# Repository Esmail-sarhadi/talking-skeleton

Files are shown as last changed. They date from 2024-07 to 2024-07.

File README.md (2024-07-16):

# Talking Skeleton with Bluetooth, RF, and MP3 Playback

## Features
- **Bluetooth Control:** Control the skeleton using a custom Android app.
- **RF Control:** Use an RF remote to trigger different actions.
- **MP3 Playback:** Play specific audio files stored on an SD card.
- **LED Indication:** Visual feedback through LEDs to indicate different parts of the skeleton.
- **Language Switching:** Switch between Persian and English for audio playback.

## Components
- **ESP32**
- **DFPlayer Mini MP3 Player**
- **Servos**
- **LEDs**
- **Bluetooth Module**
- **RF Receiver Module**
- **Custom PCB (Designed in Altium)**

## Schematic
Include a link or image of your schematic here.

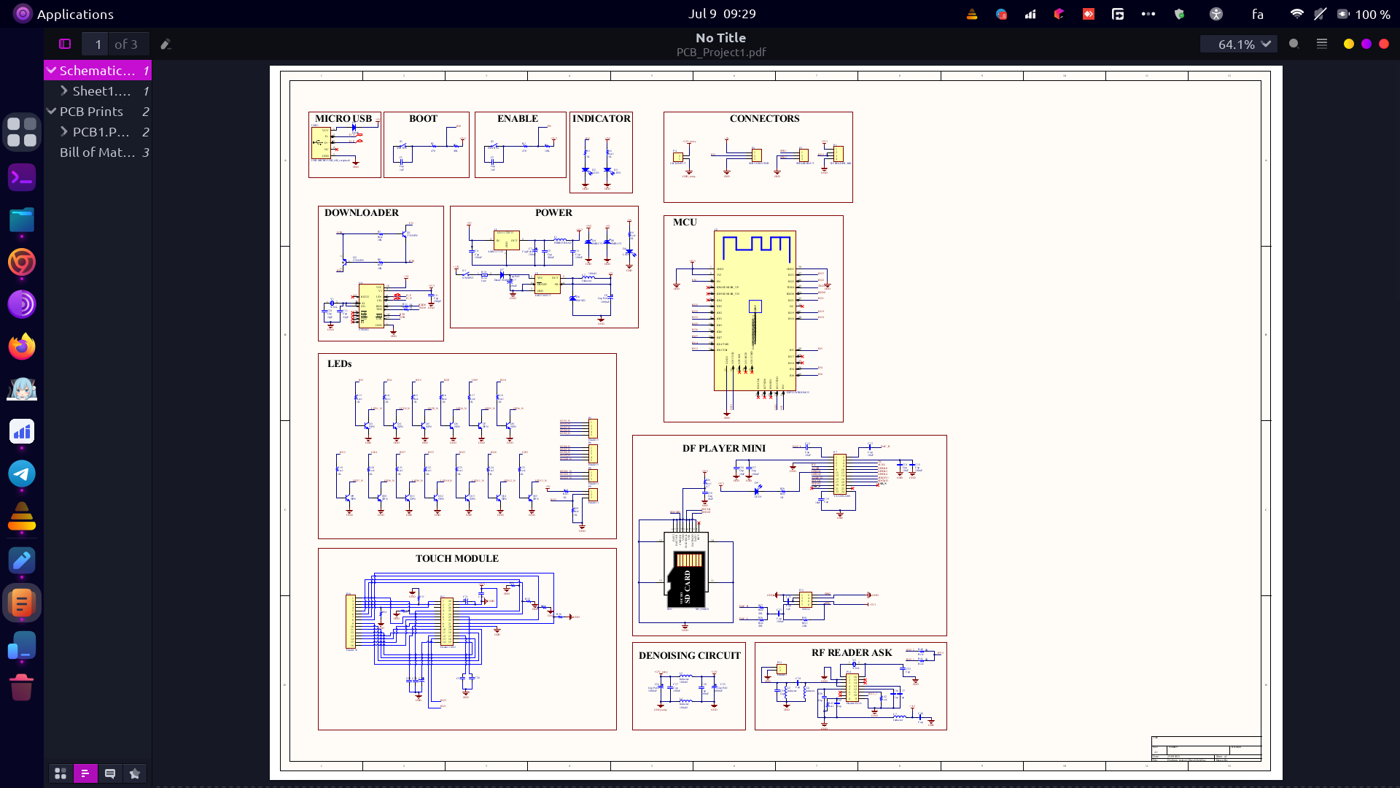
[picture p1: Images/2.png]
Schematic

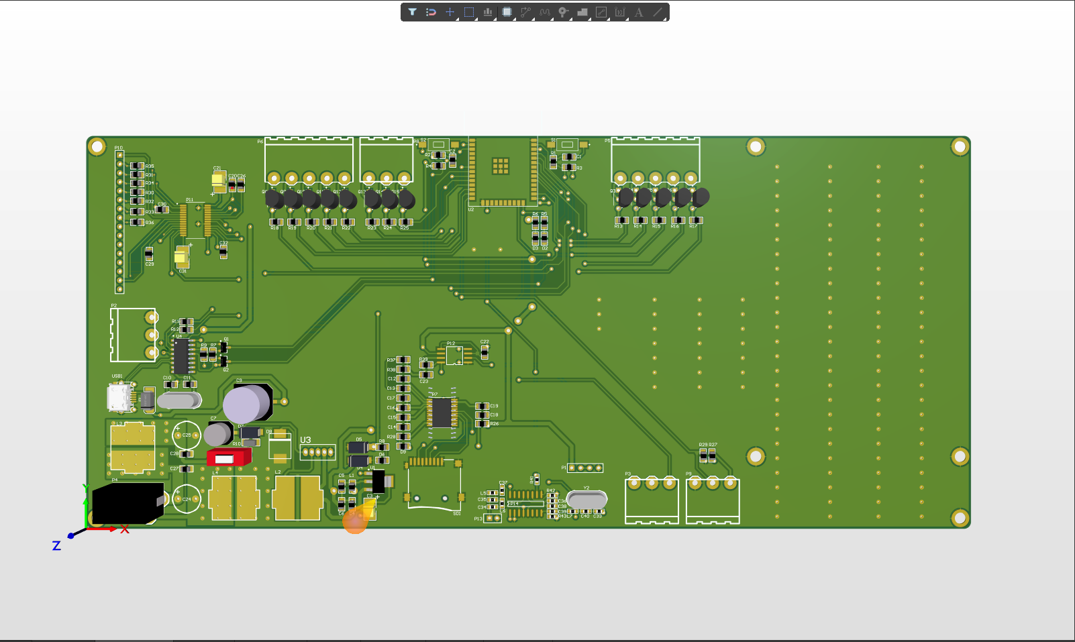
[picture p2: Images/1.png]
3D Board


## Hardware Setup
1. **ESP32:** Connect the ESP32 to your computer for programming.
2. **DFPlayer Mini MP3 Player:**
   - Connect the DFPlayer Mini to the ESP32 using UART pins.
   - Insert an SD card with the MP3 files into the DFPlayer Mini.
3. **LEDs and Servos:**
   - Connect LEDs to the designated GPIO pins on the ESP32.
   - Connect servos to the PWM pins on the ESP32.
4. **Bluetooth Module:**
   - Pair the Bluetooth module with the custom Android app.
5. **RF Receiver Module:**
   - Connect the RF receiver module to the ESP32.
6. **Power Supply:**
   - Provide appropriate power supply to all components.

## Software Setup

### Prerequisites
- Arduino IDE installed
- ESP32 board package installed in the Arduino IDE
- Required libraries: ESP32Servo, DFRobotDFPlayerMini, RCSwitch, BluetoothSerial

### Installation
1. **Clone the repository:**
   ```bash
   git clone https://github.com/esmail-sarhadi/talking-skeleton.git
   cd talking-skeleton
   ```

2. **Install Libraries:**
   - Install the necessary libraries in the Arduino IDE:
     - ESP32Servo
     - DFRobotDFPlayerMini
     - RCSwitch
     - BluetoothSerial

3. **Upload the code to the ESP32:**
   - Open the project in the Arduino IDE.
   - Connect your ESP32 to the computer.
   - Select the appropriate board and port.
   - Upload the code to your ESP32.

4. **Android App:**
   - Install the custom Android app on your device to control the skeleton via Bluetooth. (Provide link or APK file)
   - Pair your device with the skeleton.

## Usage

### Bluetooth Control
1. **Pairing:**
   - Open the Android app and pair it with the skeleton via Bluetooth.
2. **Control:**
   - Use the app to select different parts of the skeleton.
   - Trigger MP3 playback with corresponding LED indications.

### RF Control
1. **Using RF Remote:**
   - Use the RF remote to trigger specific actions.
   - The skeleton will play corresponding MP3 files and light up the relevant LEDs.

## Contributing
Feel free to contribute to this project by submitting issues or pull requests.

## License
This project is licensed under the MIT License - see the [LICENSE](LICENSE) file for details.

## Acknowledgments
- Inspiration and guidance from the maker community.
- Libraries used: ESP32Servo, DFRobotDFPlayerMini, RCSwitch, BluetoothSerial.
<h2 id="donation">Donation</h2>

<p>If you find this project helpful, consider making a donation:</p>
<p><a href="https://nowpayments.io/donation?api_key=REWCYVC-A1AMFK3-QNRS663-PKJSBD2&source=lk_donation&medium=referral" target="_blank">
     Crypto donation button by NOWPayments
</a></p>

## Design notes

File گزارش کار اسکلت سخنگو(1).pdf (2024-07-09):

## به نام خدا

# گزارش کار اسکلت سخنگو

# فهرست:

.1 معرفی اسکلت سخنگو .2 فاز های اسکلت سخنگو 2-1( طراحی و پرینت سه بعدی استخوان های انسان 2-2( طراحی برد touch 2-3( طراحی تجربه و رابط کار بری اپلیکیشن 2-4( کد نویسی بخش نرم افزار اسکلت سخنگو 2-5( کد نویسی بخش سخت افزار اسکلت سخنگو 2-6( مونتاژ قطعات الکترونیکی و ماژول های اسکلت سخنگو .3 کاربرد اسکلت سخنگو

## معرفی اسکلت سخنگو

اسکلت سخنگو یکی از محصوالت شرکت ساناست که به وسیله کنترل رادیویی، اپلیکیشن و لمس قسمت های مختلف، توضیحات مربوطه شرح داده می شود.

## فاز های اسکلت سخنگو

## طراحی و پرینت سه بعدی استخوان های انسان

فیالمنت PLA پالس سفید ایسان eSUN+PLA یک ماده پرینت سه بعدی است که توسط شرکت ایسان eSUN تولید شده است فیالمنت PLA پالس ایسان یک نسخه بهبود یافته از eSUN PLA معمولی است که با مخلوطی از اصالح کننده ها، افزدونی ها و رنگدانه ها غنی شده است که خواص مکانیکی و زیبایی شناختی آن را بهبود می بخشد و در عین حال یک رنگ سفید صاف را ارائه می دهد.
برای پرینت استخوان های انسان از PLA پالس سفید ایسان استفاده شده است.

مشخصات:

ماده: +PLA
برند: ESUN
رنگ: سفید
تلرانس: 0.05 میلی متر
قطر: 1.75 میلی متر
دمای چاپ: -225 205 درجه سانتی گراد

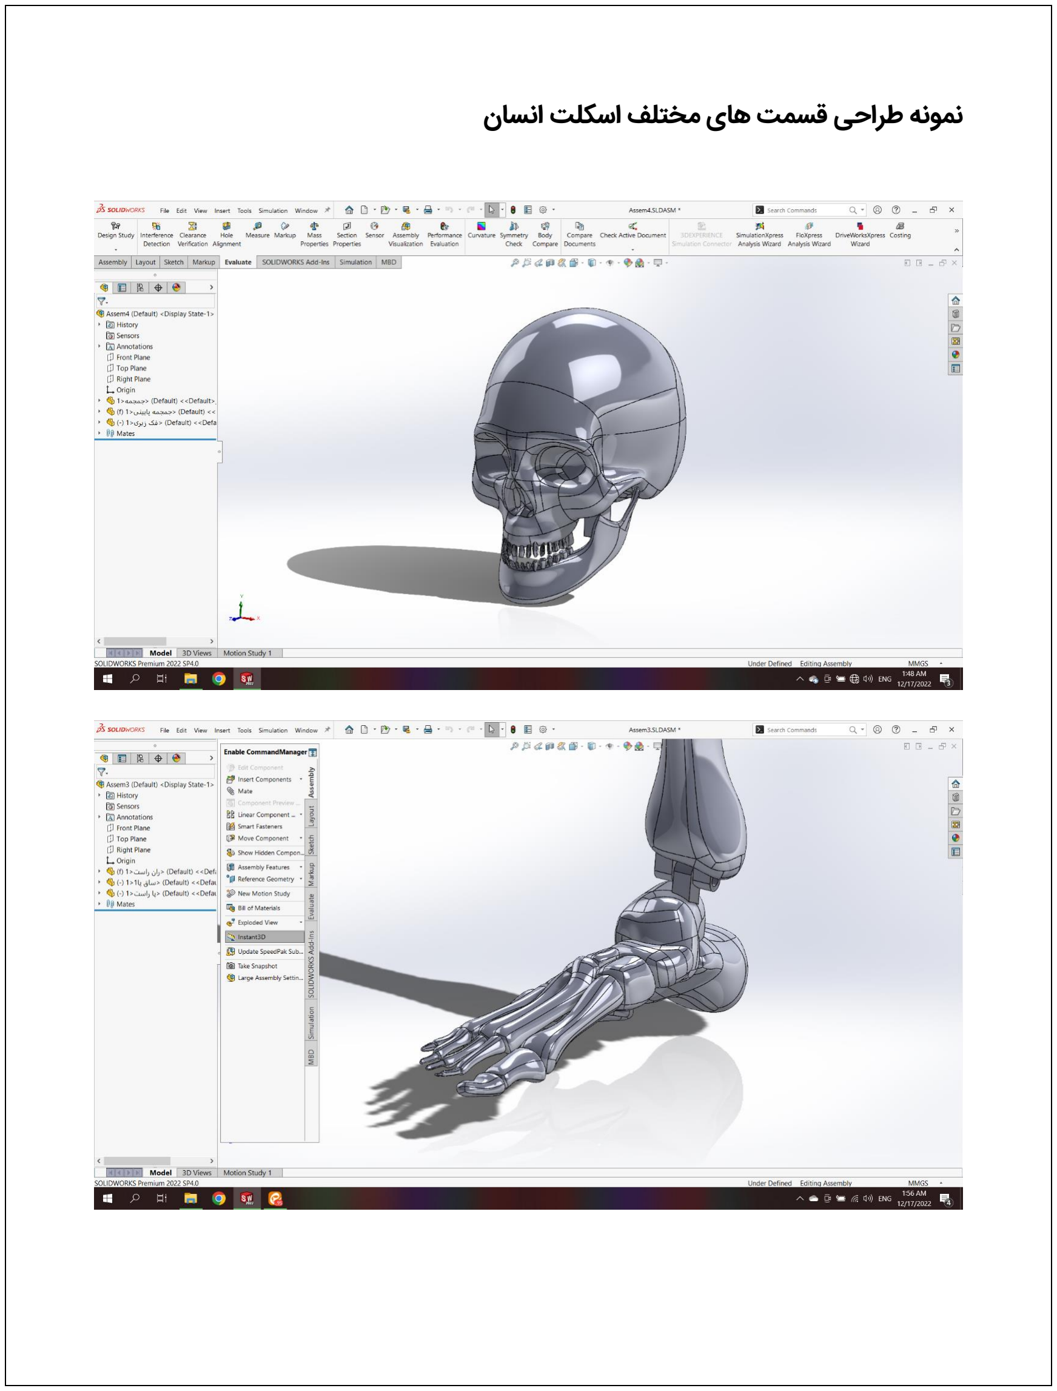
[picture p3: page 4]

نمونه طراحی قسمت های مختلف اسکلت انسان

پرینت قسمت های مختلف اسکلت انسان

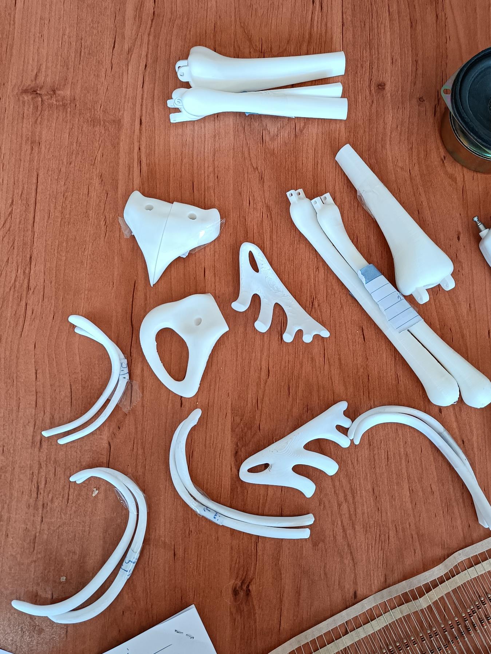
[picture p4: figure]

جهت روشن شدن و قابلیت لمس هر قسمت از موالژ اسکلت انسان بوسیله ی led و کابل ماژول تاچ، و پخش شدن توضیحات همان قسمت، اکثر استخوان ها به اندازه 4 میلی متر تو خالی پرینت شده اند.
مقدار شبکه بندی موالژ پرینت شده توسط پرینتر سه بعدی برابر با 30 درصد است. در نتیجه 30 درصد استخوان های موالژ تو خالی هستند.

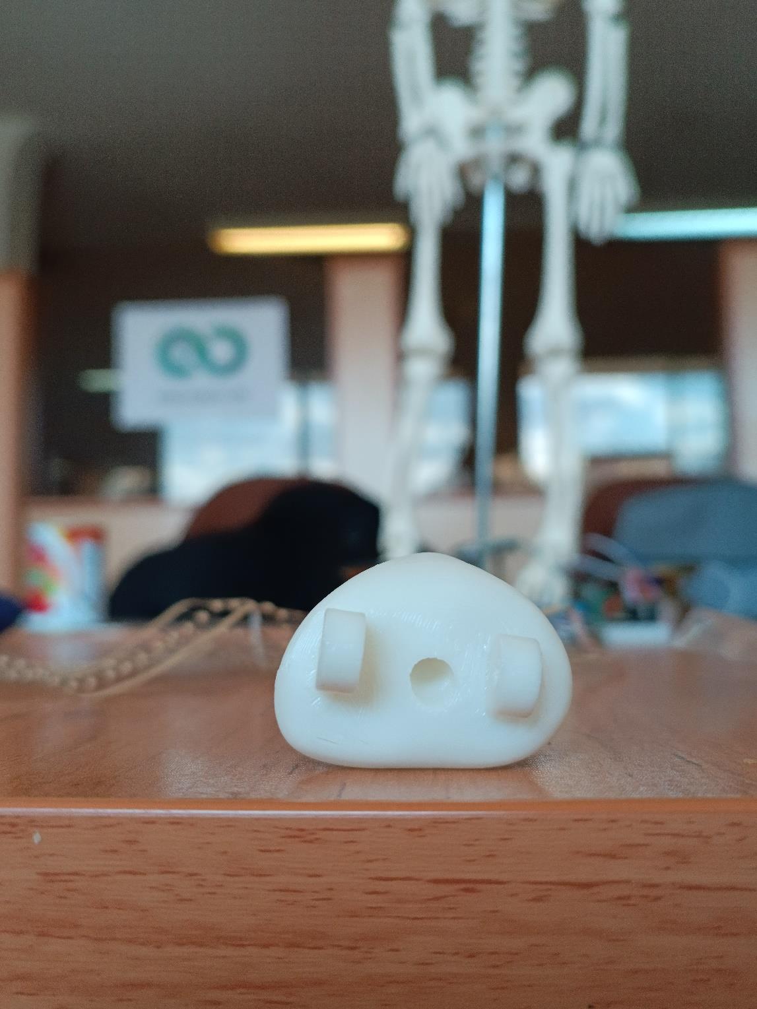
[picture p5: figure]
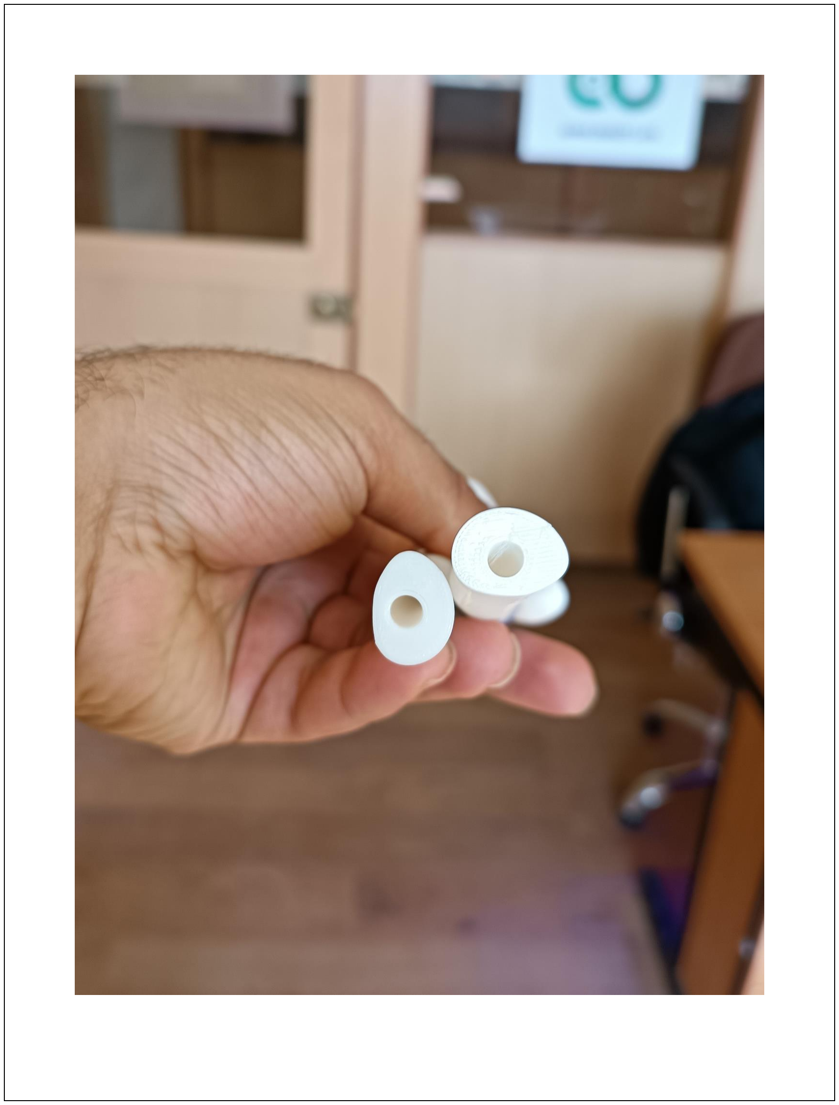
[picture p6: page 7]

## طراحی برد تاچ

از آنجایی که اسکلت سخنگو به گونه ای طراحی شده که عالوه بر کنترل و اپلیکیشن، با لمس هر قسمت از اسکلت توضیحات آن پخش شود، برد تاچ طراحی و پیاده سازی شده است. از آن جهت که استخوان هایی که قابلیت توضیح داشتند 13 عدد بودند از 229ttp ic در حالت 16 کلید برای ماژول touch استفاده شده است.

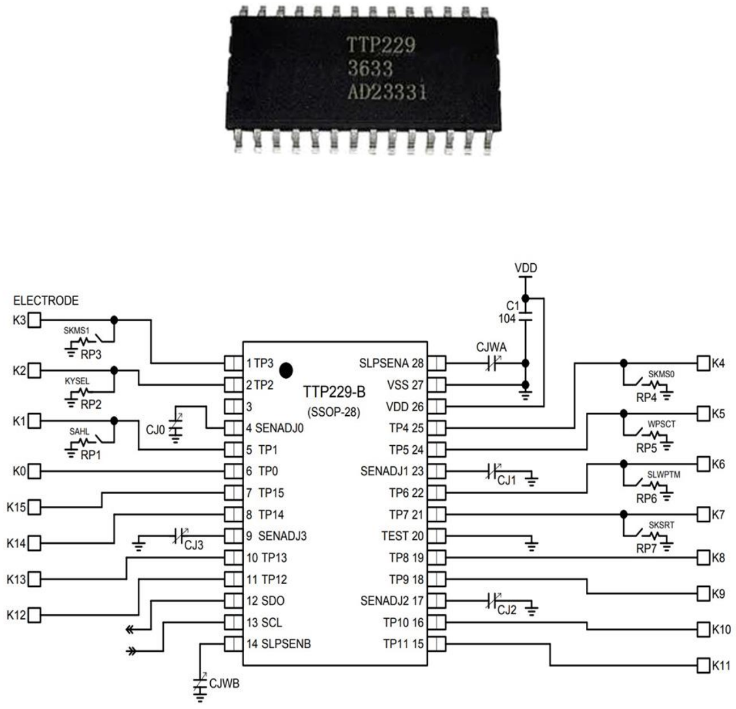
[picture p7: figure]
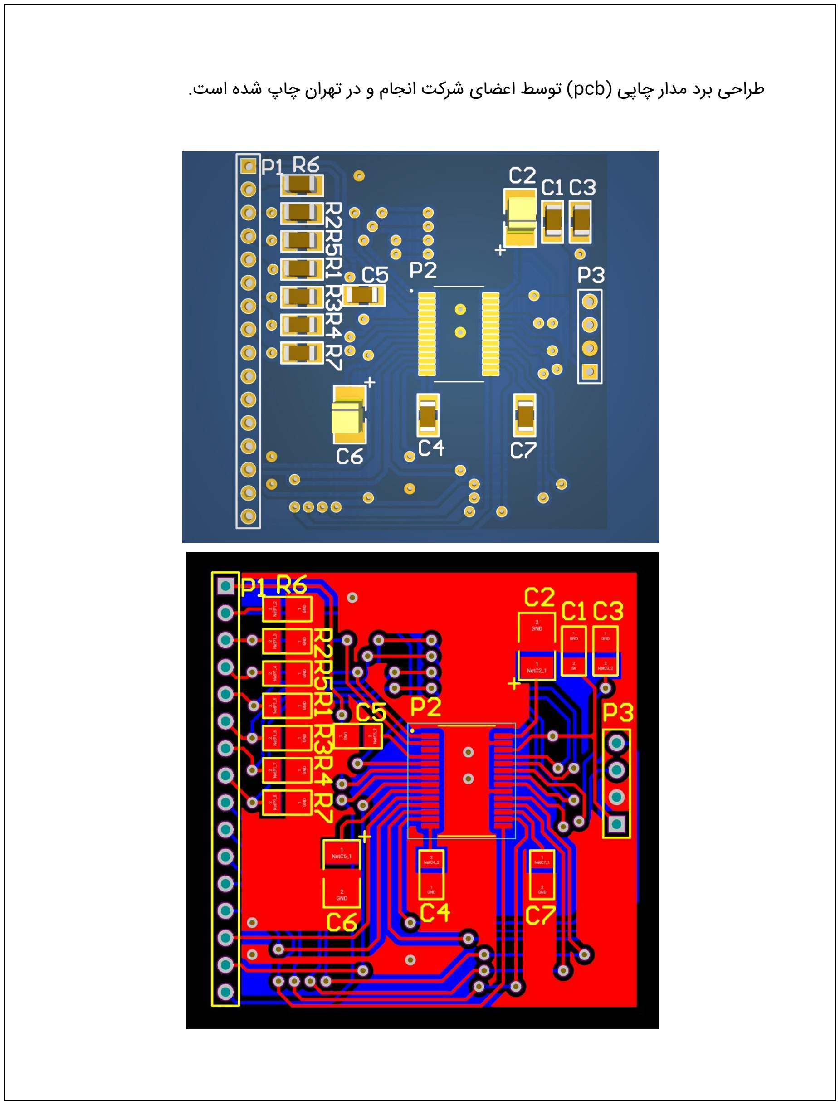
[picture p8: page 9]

طراحی برد مدار چاپی )pcb )توسط اعضای شرکت انجام و در تهران چاپ شده است.

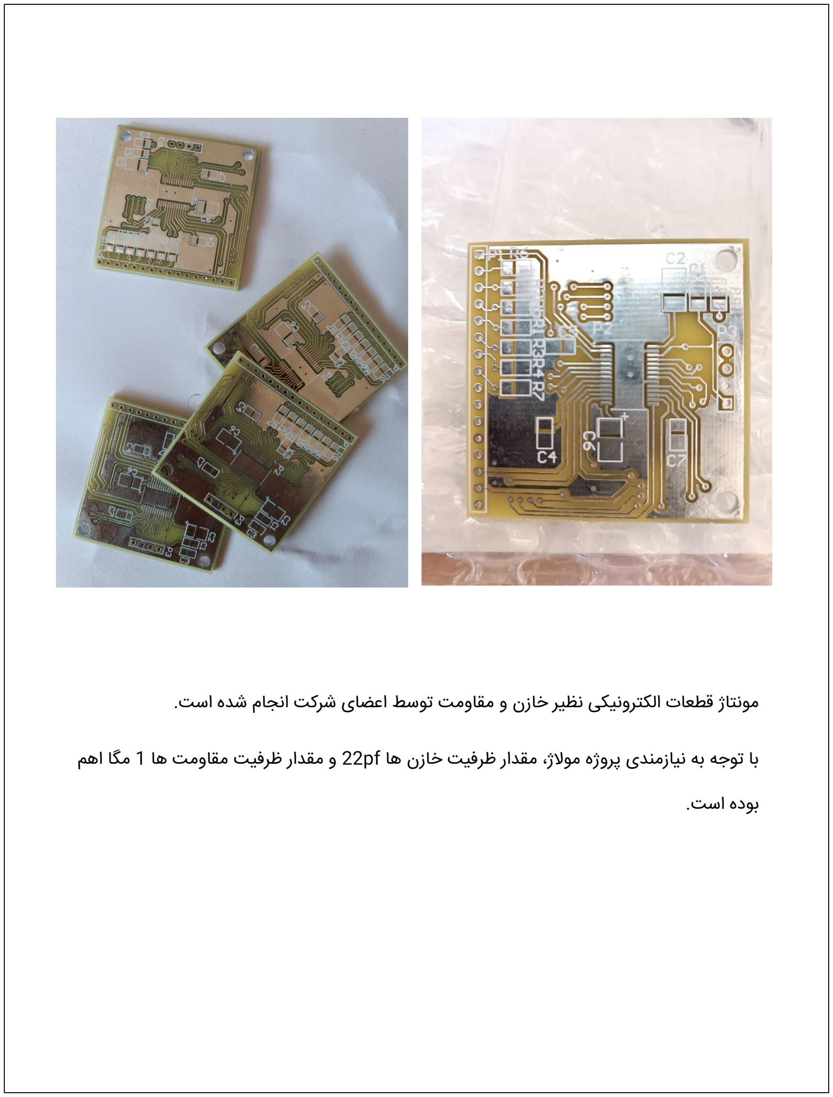
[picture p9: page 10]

مونتاژ قطعات الکترونیکی نظیر خازن و مقاومت توسط اعضای شرکت انجام شده است.

با توجه به نیازمندی پروژه موالژ، مقدار ظرفیت خازن ها pf22 و مقدار ظرفیت مقاومت ها 1 مگا اهم بوده است.

## طراحی تجربه و رابط کاربری اپلیکیشن اسکلت سخنگو

برای مدت زمان بسیار زیادی، طراحی به معنای طراحی گرافیکی بود )یعنی ظاهر محصول(. اما با پیشرفت تکنولوژی دیجیتال و انتظارات ما از تعامالت دیجیتالی، بیشتر به ”احساسی“ که محصول به وجود می آورد پرداخته شد. که به آن تجربه کاربری نیز گفته می شود. اگر UX تجربه ای باشد که کاربر در زمان کار با محصول دارد، طراحی تجربه کاربری فرآیندی است که از طریق آن طراح سعی میکند تشخیص دهد تجربه ای که به وجود میآید چیست!

بنابراین با توجه به تحقیقات و مشاهدات انجام شده در رابطه با کاربران که شامل دانش آموزان، دانشجویان، معلمان، اساتید و ... می شوند، رابط کاربری به گونه ای ساده و صریح طراحی شده است تا همه ی کاربران به راحتی و بدون نیاز به یادگیری قبلی بتوانند از اپلیکیشن استفاده کنند.

برای طراحی اپلیکشن از سه رنگ سبز، سفید و مشکی )سبز = مورد پسند اکثر افراد، کنتراست الزم با رنگ های سفید و مشکی
سفید = کمک به سادگی محصول
مشکی = خوانایی باال( استفاده شده است.
- صفحه screen-splash( صفحه معرفی( به گونه ای طراحی شده که در عین سادگی، محصول اسکلت سخنگو را معرفی میکند.

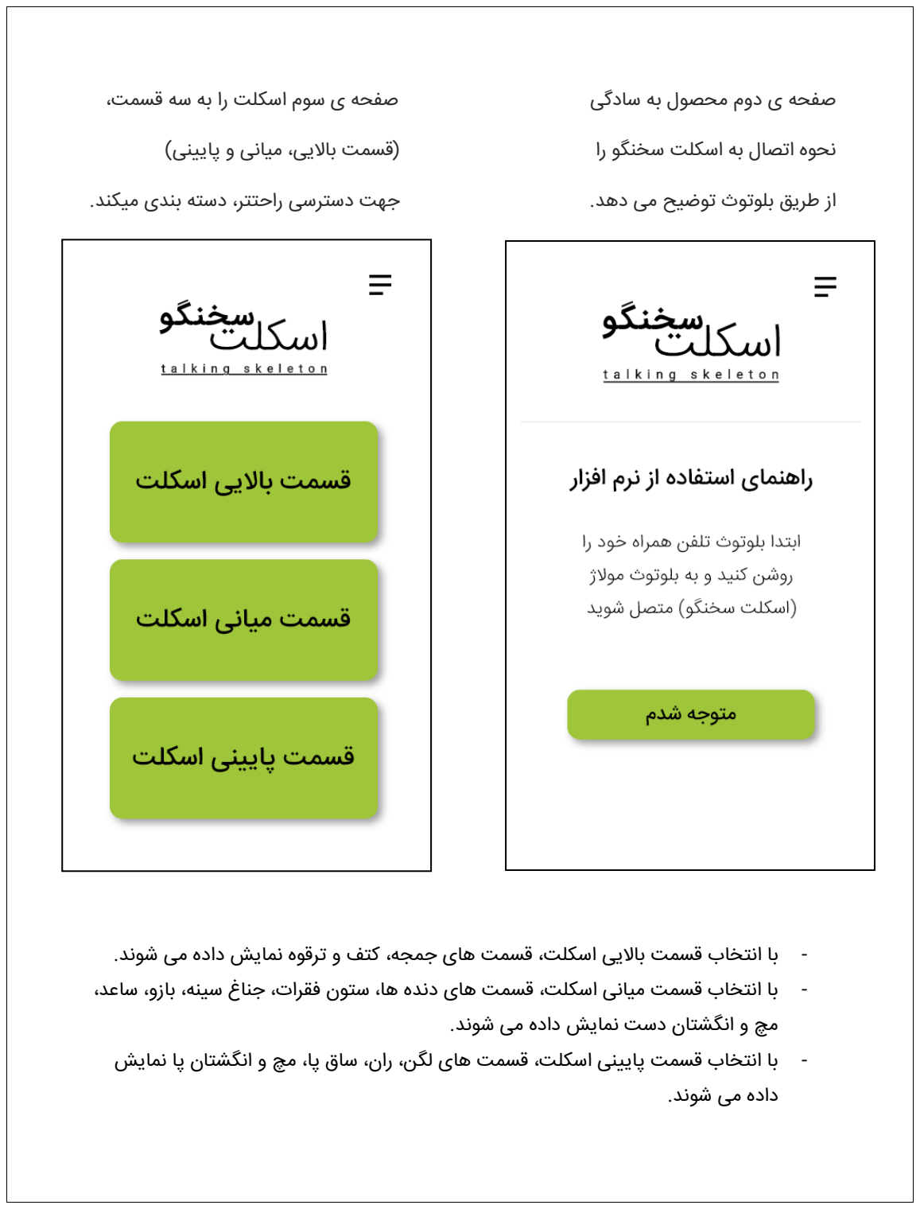
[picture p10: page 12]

صفحه ی دوم محصول به سادگی صفحه ی سوم اسکلت را به سه قسمت، نحوه اتصال به اسکلت سخنگو را )قسمت باالیی، میانی و پایینی( از طریق بلوتوث توضیح می دهد. جهت دسترسی راحتتر، دسته بندی میکند.

- با انتخاب قسمت باالیی اسکلت، قسمت های جمجه، کتف و ترقوه نمایش داده می شوند.
- با انتخاب قسمت میانی اسکلت، قسمت های دنده ها، ستون فقرات، جناغ سینه، بازو، ساعد، مچ و انگشتان دست نمایش داده می شوند.
- با انتخاب قسمت پایینی اسکلت، قسمت های لگن، ران، ساق پا، مچ و انگشتان پا نمایش داده می شوند.

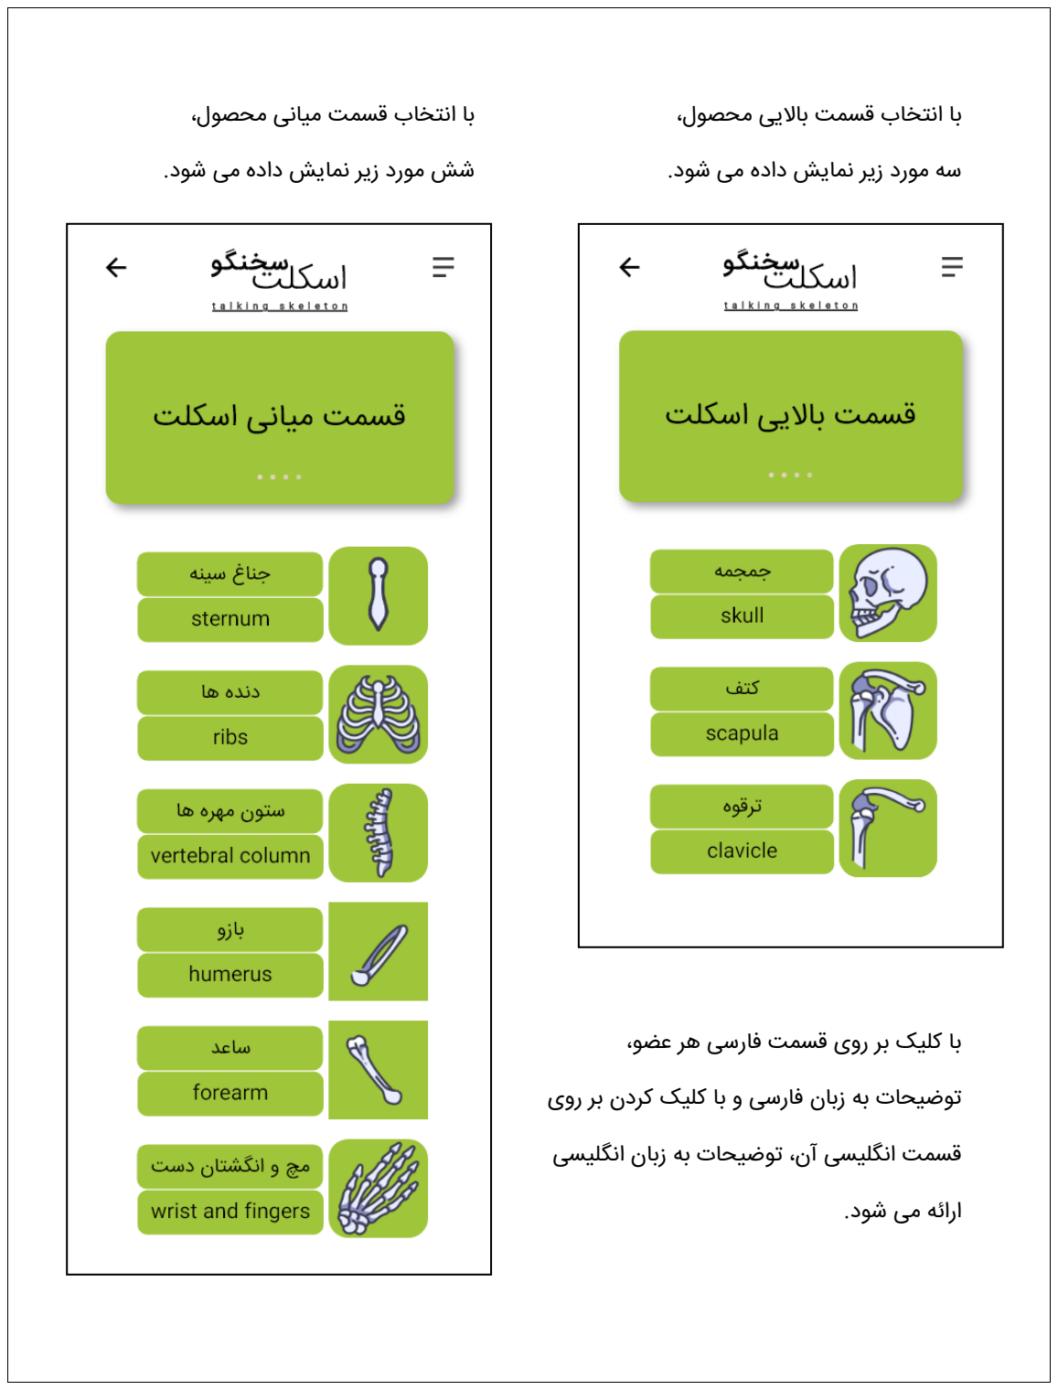
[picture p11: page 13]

با انتخاب قسمت باالیی محصول، با انتخاب قسمت میانی محصول، سه مورد زیر نمایش داده می شود. شش مورد زیر نمایش داده می شود.

با کلیک بر روی قسمت فارسی هر عضو، توضیحات به زبان فارسی و با کلیک کردن بر روی قسمت انگلیسی آن، توضیحات به زبان انگلیسی ارائه می شود.

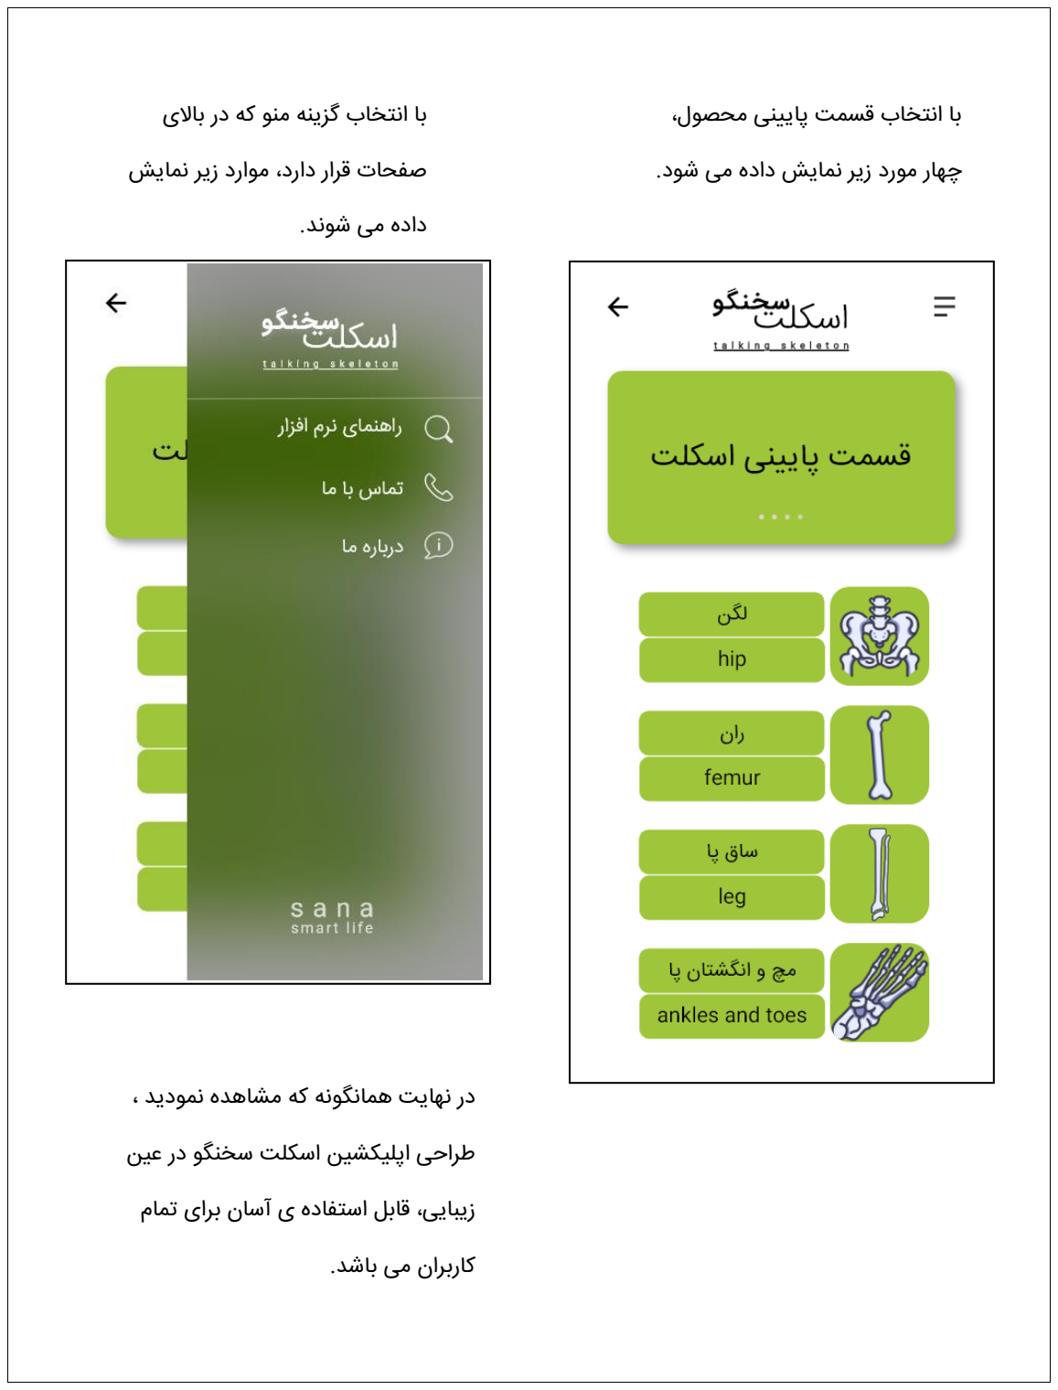
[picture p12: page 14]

با انتخاب قسمت پایینی محصول، با انتخاب گزینه منو که در باالی چهار مورد زیر نمایش داده می شود. صفحات قرار دارد، موارد زیر نمایش داده می شوند.

در نهایت همانگونه که مشاهده نمودید ، طراحی اپلیکشین اسکلت سخنگو در عین زیبایی، قابل استفاده ی آسان برای تمام کاربران می باشد.

## کد نویسی بخش نرم افزار اسکلت سخنگو

بخش نرمافزار موالژ سخنگو از دو قسمت رابط کاربری و دستورات ارسال و دریافت داده تشکیلشده است. این گزارش مربوط به دستورات ارسال و دریافت اطالعات است که به زبان کاتلین نوشتهشده است.
عملکرد کلی نرم افزار
این اپ دستورات مربوط به پخش یا تغییر زبان گفتار موالژ را به قسمت سختافزار ارسال میکند. این کار از طریق اتصال بلوتوث صورت میگیرد. در ابتدا باید بلوتوث تلفن همراه به بلوتوث سختافزار دستگاه متصل شود تا امکان تبادل اطالعات وجود داشته باشد. سپس از طریق تابعهای تعریف شده دستورات الزم از طریق قسمتهای تعریف شده در رابط کاربری ارسال میشود.

در این خط کد برای دستگاه مشخص می ک ند که قابلیت پشتیبانی از بلوتوث را دارد یا خیر. ممکن است که به خاطر عدم دسترسی دادن به نرمافزار امکان دسترسی به بلوتوث وجود نداشته باشد یا اموالتور ها و شبیهسازهای مجازی تلفن همراه ممکن است این قابلیت و پشتیبانی را نداشته باشند.

دستور باال در صورتی اجرا میشود که کاربر وارد اپلیکیشن شده ولی بلوتوث دستگاه روشن نیست. قطعه کد باال درخواست روشن شدن بلوتوث در صورت خاموش بودن آن را نمایش میدهد.

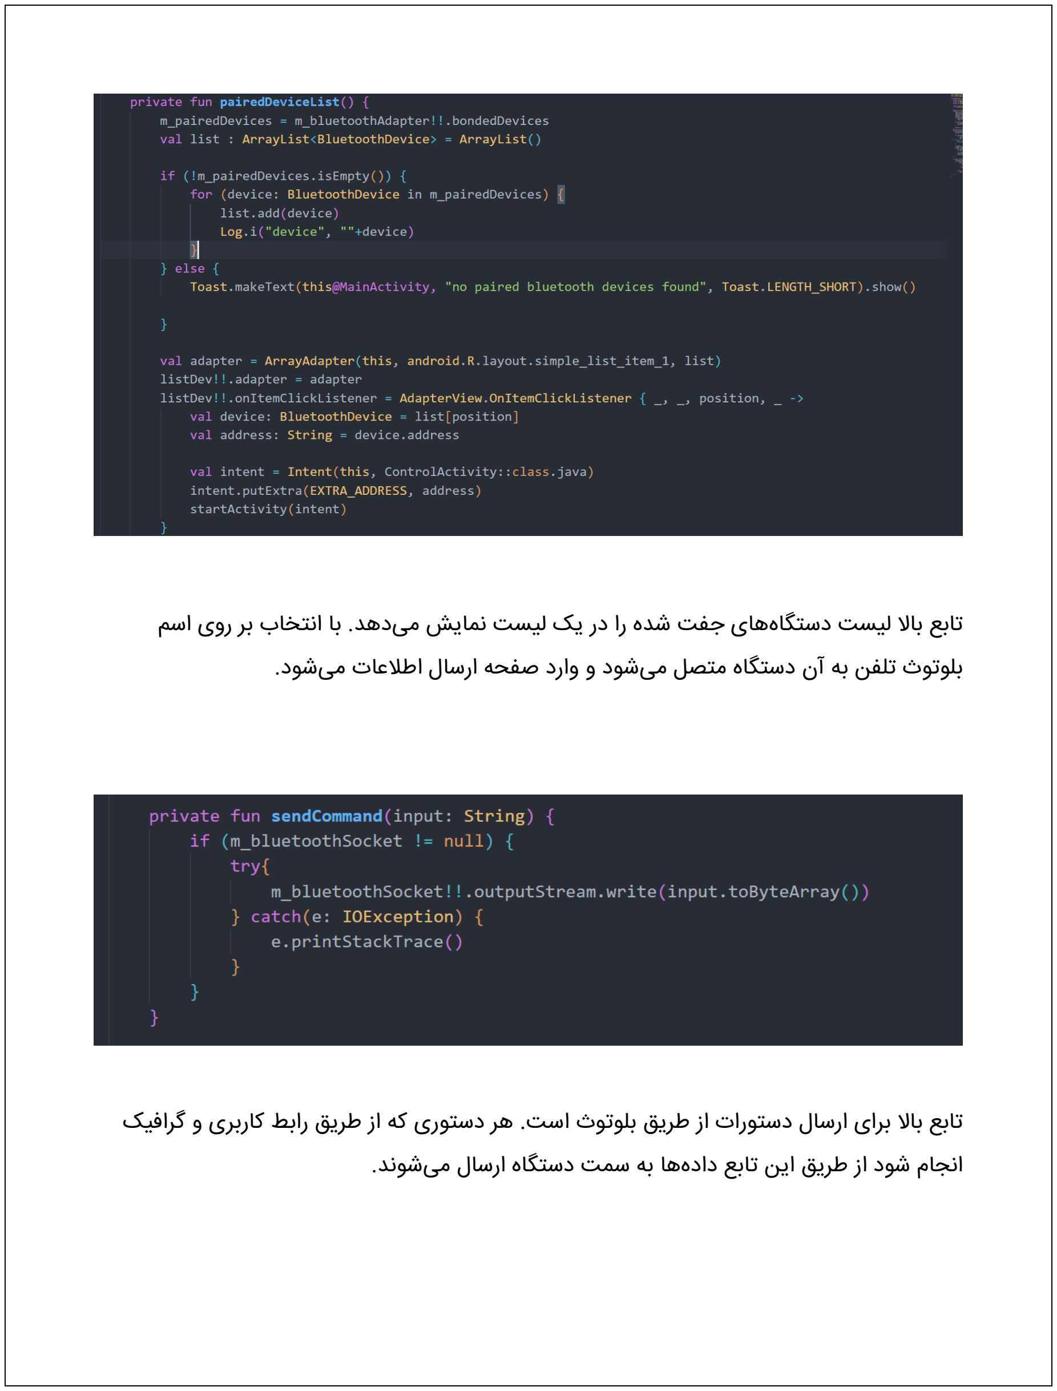
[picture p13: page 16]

تابع باال لیست دستگاههای جفت شده را در یک لیست نمایش میدهد. با انتخاب بر روی اسم بلوتوث تلفن به آن دستگاه متصل میشود و وارد صفحه ارسال اطالعات میشود.

تابع باال برای ارسال دستورات از طریق بلوتوث است. هر دستوری که از طریق رابط کاربری و گرافیک انجام شود از طریق این تابع دادهها به سمت دستگاه ارسال میشوند.

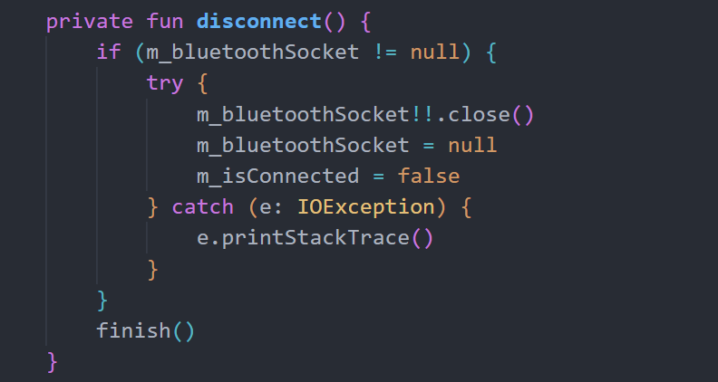
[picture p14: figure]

این تابع نیز برای قطع اتصال بلوتوث میباشد. از طریق این تابع اتصالی که بین دو بلوتوث تلفن و دستگاه برقرارشده است قطعشده و دیگر امکان تبادل اطالعات وجود ندارد.

## کد نویسی بخش سخت افزار اسکلت سخنگو

بخش سخت افزار موالژ سخنگو وظیفه دریافت داده از اپلیکیشن و اجرای دستورات دریافتی را بر عهده دارد. ازجمله ماژول ها و قطعات برای این بخش میتوان به دریافتکننده امواج رادیویی، بلندگو، ماژول پخش صدا، میکرو کنترلر و هسته پردازشگر دادهها اشاره کرد.

## عملکرد کلی دستگاه

پخش صوت مربوط به هر بخش از دو طریق کنترل امواج رادیویی و اپلیکیشن از طریق بلوتوث :

.1 کنترل امواج رادیویی: کنترل رادیویی دارای 16 کلید است که با فشردن هر کلید کد رادیویی مربوط به آن کلید از طریق موج رادیویی 433 مگاهرتز ارسال میشود. این موج توسط گیرنده رادیویی که به میکرو کنترلر متصل است دریافت میشود و پس از بررسی کد ارسال دستور مربوط به آن اجرا میشود. کلید شماره 1 مربوط به تغییر زبان گفتار موالژ میباشد که با فشردن یکبار آن زبان آن از فارسی به انگلیسی تغییر پیدا میکند. با فشردن دوباره آن زبان گفتار به فارسی بازمیگردد. کلیدهای 2 تا 14 مربوط به بخشهای مختلف استخوانهای موالژ میباشد که با فشردن هر کلید توضیحات مربوط به آن بخش به زبان فارسی یا انگلیسی پخش می شود. کلیدهای 15 و 16 برای تنظیم صدای موالژ در نظر گرفتهشده است.

.2 اپلیکیشن: عملکرد قسمت اپلیکیشن نیز مانند امواج رادیویی است ولی تفاوتهایی در این بخش وجود دارد. فرمانهای ارسالی این بخش از طریق بلوتوث صورت میگیرد. به دلیل اینکه 32esp دارای ماژول بلوتوث میباشد لذا نیازی به استفاده از ماژول های بلوتوث (-05HC (و مانند آن نیست. اپلیکیشن از طریق بلوتوث به دستگاه متصل می شود و تبادل پیام از این طریق صورت میگیرد.

## ت وضیحات مربوط به کدهای سخت افزار

در ابتدا کتابخانههای موردنیاز برای استفاده از بلوتوث و ماژول رادیویی باید به برنامه اضافه شود.

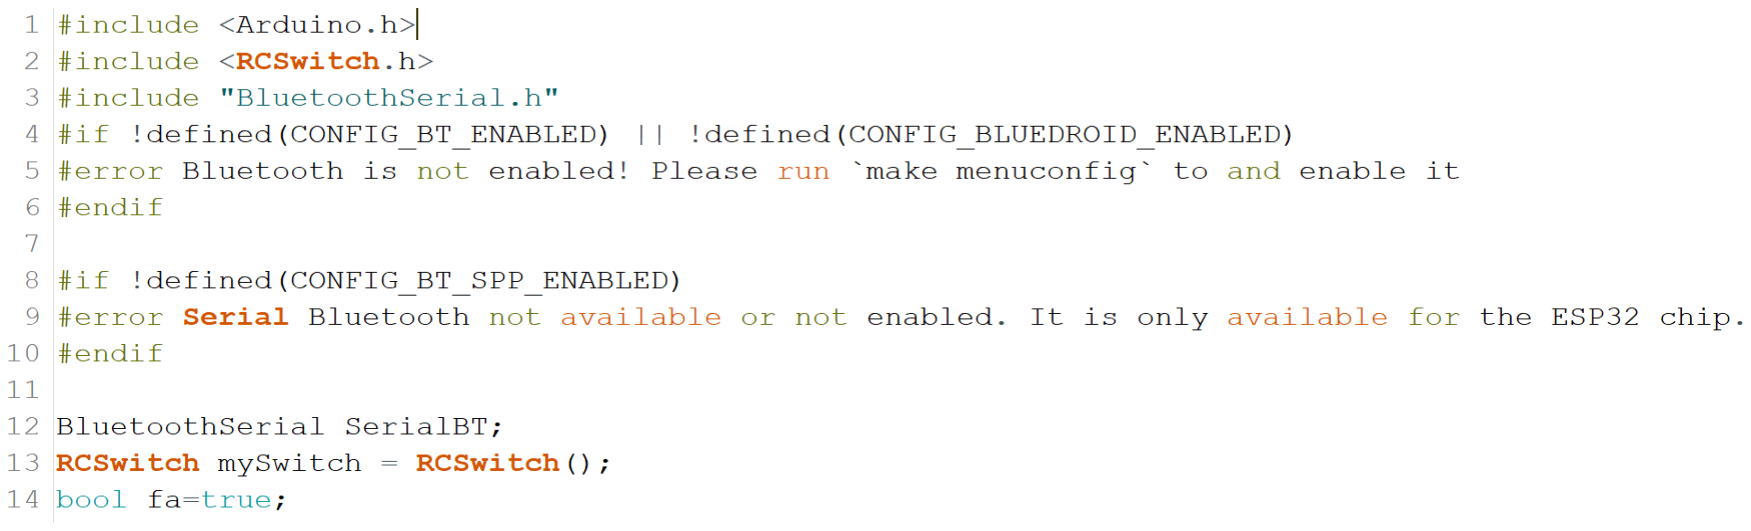
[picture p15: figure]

کتابخانه RCSwitch : با استفاده از این کتابخانه میتوان ارسال و دریافت امواج رادیویی را با استفاده از ماژول های گیرنده یا فرستنده انجام داد. در ادامه نیز نام mySwitch برای استفاده از این کتابخانه در نظر گرفتهشده است. کتابخانه BluetoothSerial: با استفاده از این کتابخانه میتوان ارسال و دریافت اطالعات را با استفاده از بلوتوث انجام داد. در ادامه نیز نام SerialBT برای استفاده از این کتابخانه تعریف شده است.
اطالعاتی که بعد از کتابخانهها آمده است مربوط به کارهایی که باید برای عدم فعال شدن بلوتوث صورت گیرد نوشتهشده است.

در این قسمت بلوتوث دستگاه با نام test32ESP فعال میشود و بلوتوث دستگاه با این نام شناخته میشود. در خط بعدی نیز پیغامی برای فعال شدن بلوتوث بر روی صفحه سریال برنامه نمایش داده میشود.

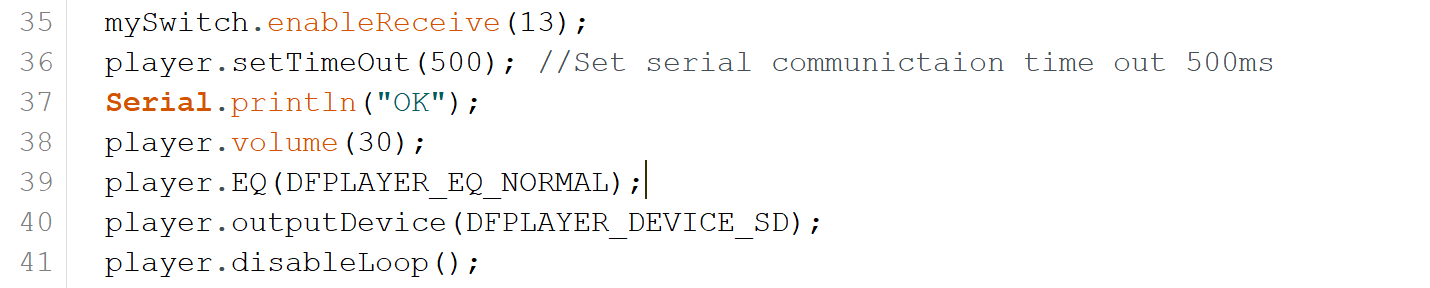
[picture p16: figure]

دستور (13)enableReceive.mySwitch: این دستور نشان میدهد که ماژول موج رادیویی از نوع گیرنده (receive (و بر روی پایه 13 میکرو فعال شده است. ازاینپس برای دریافت اطالعات گرفتهشده باید پایه 13 را خوانده و از آن برای خواندن استفاده میکنیم. دستورات بعد از آن مربوط به تنظیمات صدا و مدت زمان تایم اوت دستورات برای پخش کننده را انجام میدهد.

تابع play: این تابع برای پخش قسمت مربوط به هر اندام و استخوان میباشد. ورودی این تابع یک مقدار عددی است که متناسب با عدد ورودی، استخوان مربوط با آن قسمت را پخش می کند.

در تابع loop شرط وجود داده از طرف بلوتوث یا ماژول گیرنده رادیویی را بررسی میکند. اگر اطالعاتی از طریق بلوتوث یا گیرنده رادیویی دریافت شود آن اطالعات را خوانده و سپس در مورد اینکه چه دادهای دریافت شده است عملیات مربوط به آن داده را انجام میدهد. اگر داده دریافتی تغییر زبان باشد زبان گفتار موالژ را تغییر میدهد و اگر داده مربوط به تشریح قسمت مختلف موالژ باشد متناسب با داده ورودی آن قسمت را پخش میکند.

## مونتاژ قطعات الکترونیکی و ماژول های اسکلت سخنگو

در جهت پخش توضیحات مربوط به هر قسمت از اس کلت، 2 عدد اسپیکر و یک آمپلی فایر w 100 استفاده شده است که برای کنترل آن ، به میکروکنترلی به نام esp متصل میشود .

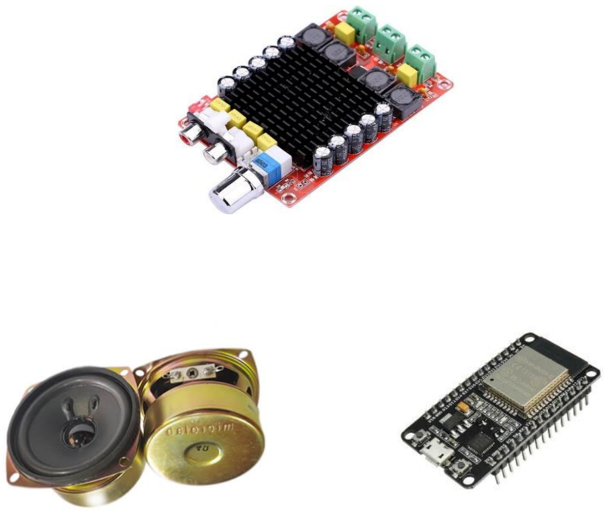
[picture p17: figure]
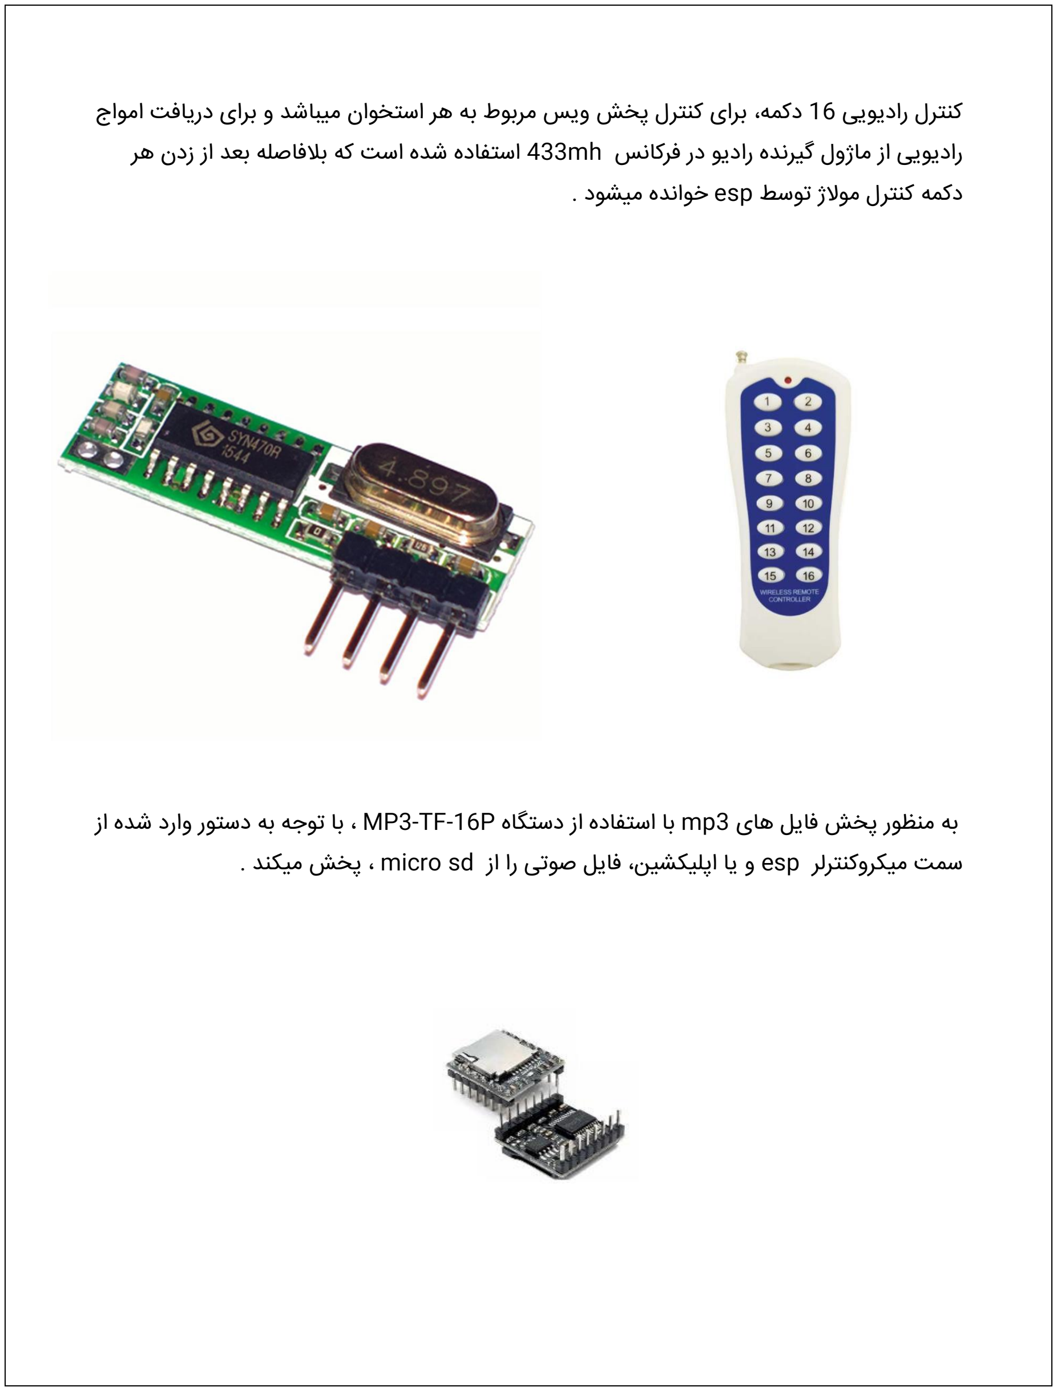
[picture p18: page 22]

کنترل رادیویی 16 دکمه، برای کنترل پخش ویس مربوط به هر استخوان میباشد و برای دریافت امواج رادیویی از ماژول گیرنده رادیو در فرکانس mh433 استفاده شده است که بالفاصله بعد از زدن هر دکمه کنترل موالژ توسط esp خوانده میشود .

به منظور پخش فایل های 3mp با استفاده از دستگاه P-16TF3-MP ، با توجه به دستور وارد شده از سمت میکروکنترلر esp و یا اپلیکشین، فایل صوتی را از sd micro ، پخش میکند .

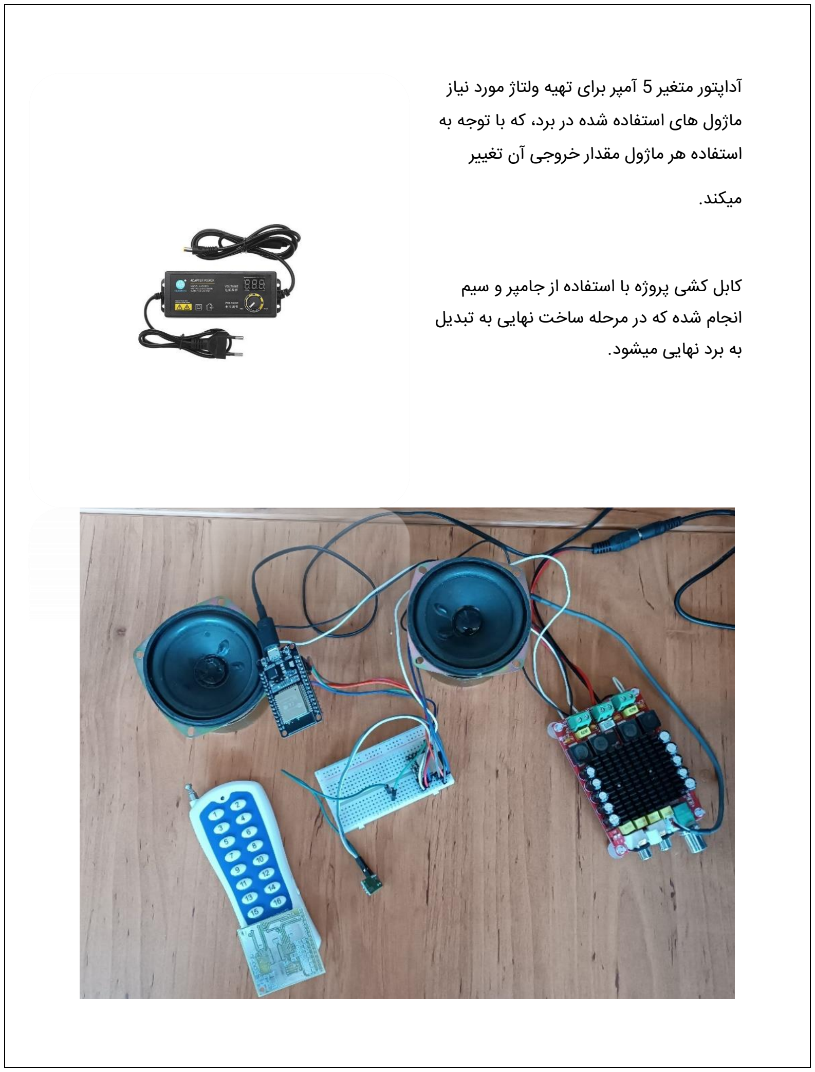
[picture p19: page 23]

آداپتور متغیر 5 آمپر برای تهیه ولتاژ مورد نیاز ماژول های استفاده شده در برد ، که با توجه به استفاده هر ماژول مقدار خروجی آن تغییر میکند.

ک ابل کشی پروژه با استفاده از جامپر و سیم انجام شده که در مرحله ساخت نهایی به تبدیل به برد نهایی میشود .

## کاربرد اسکلت سخنگو

همانطور که در ابتدا مطالعه نمودید، اسکلت سخنگو یکی از محصوالت شرکت ساناست که در جهت یادگیری استخوان های بدن انسان برای دانش آموزان، دانشجویان و ... در آموزشگاه ها، آزمایشگاه ها، مدارس و دانشگاه ها، بس یار کاربردی و مفید است. به طوری که با مشخص کردن استخوان مورد نظر بوسیله کنترل رادیویی، اپلیکیشن یا لمس استخوان، مشخصات مربوطه شرح و باعث تسریع در روند یادگیری می شود.

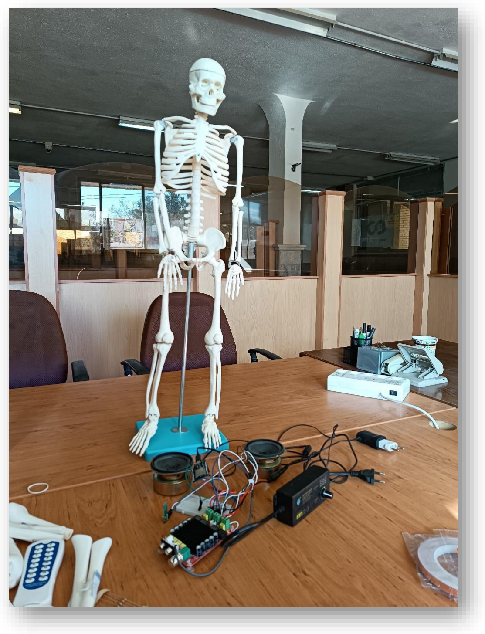
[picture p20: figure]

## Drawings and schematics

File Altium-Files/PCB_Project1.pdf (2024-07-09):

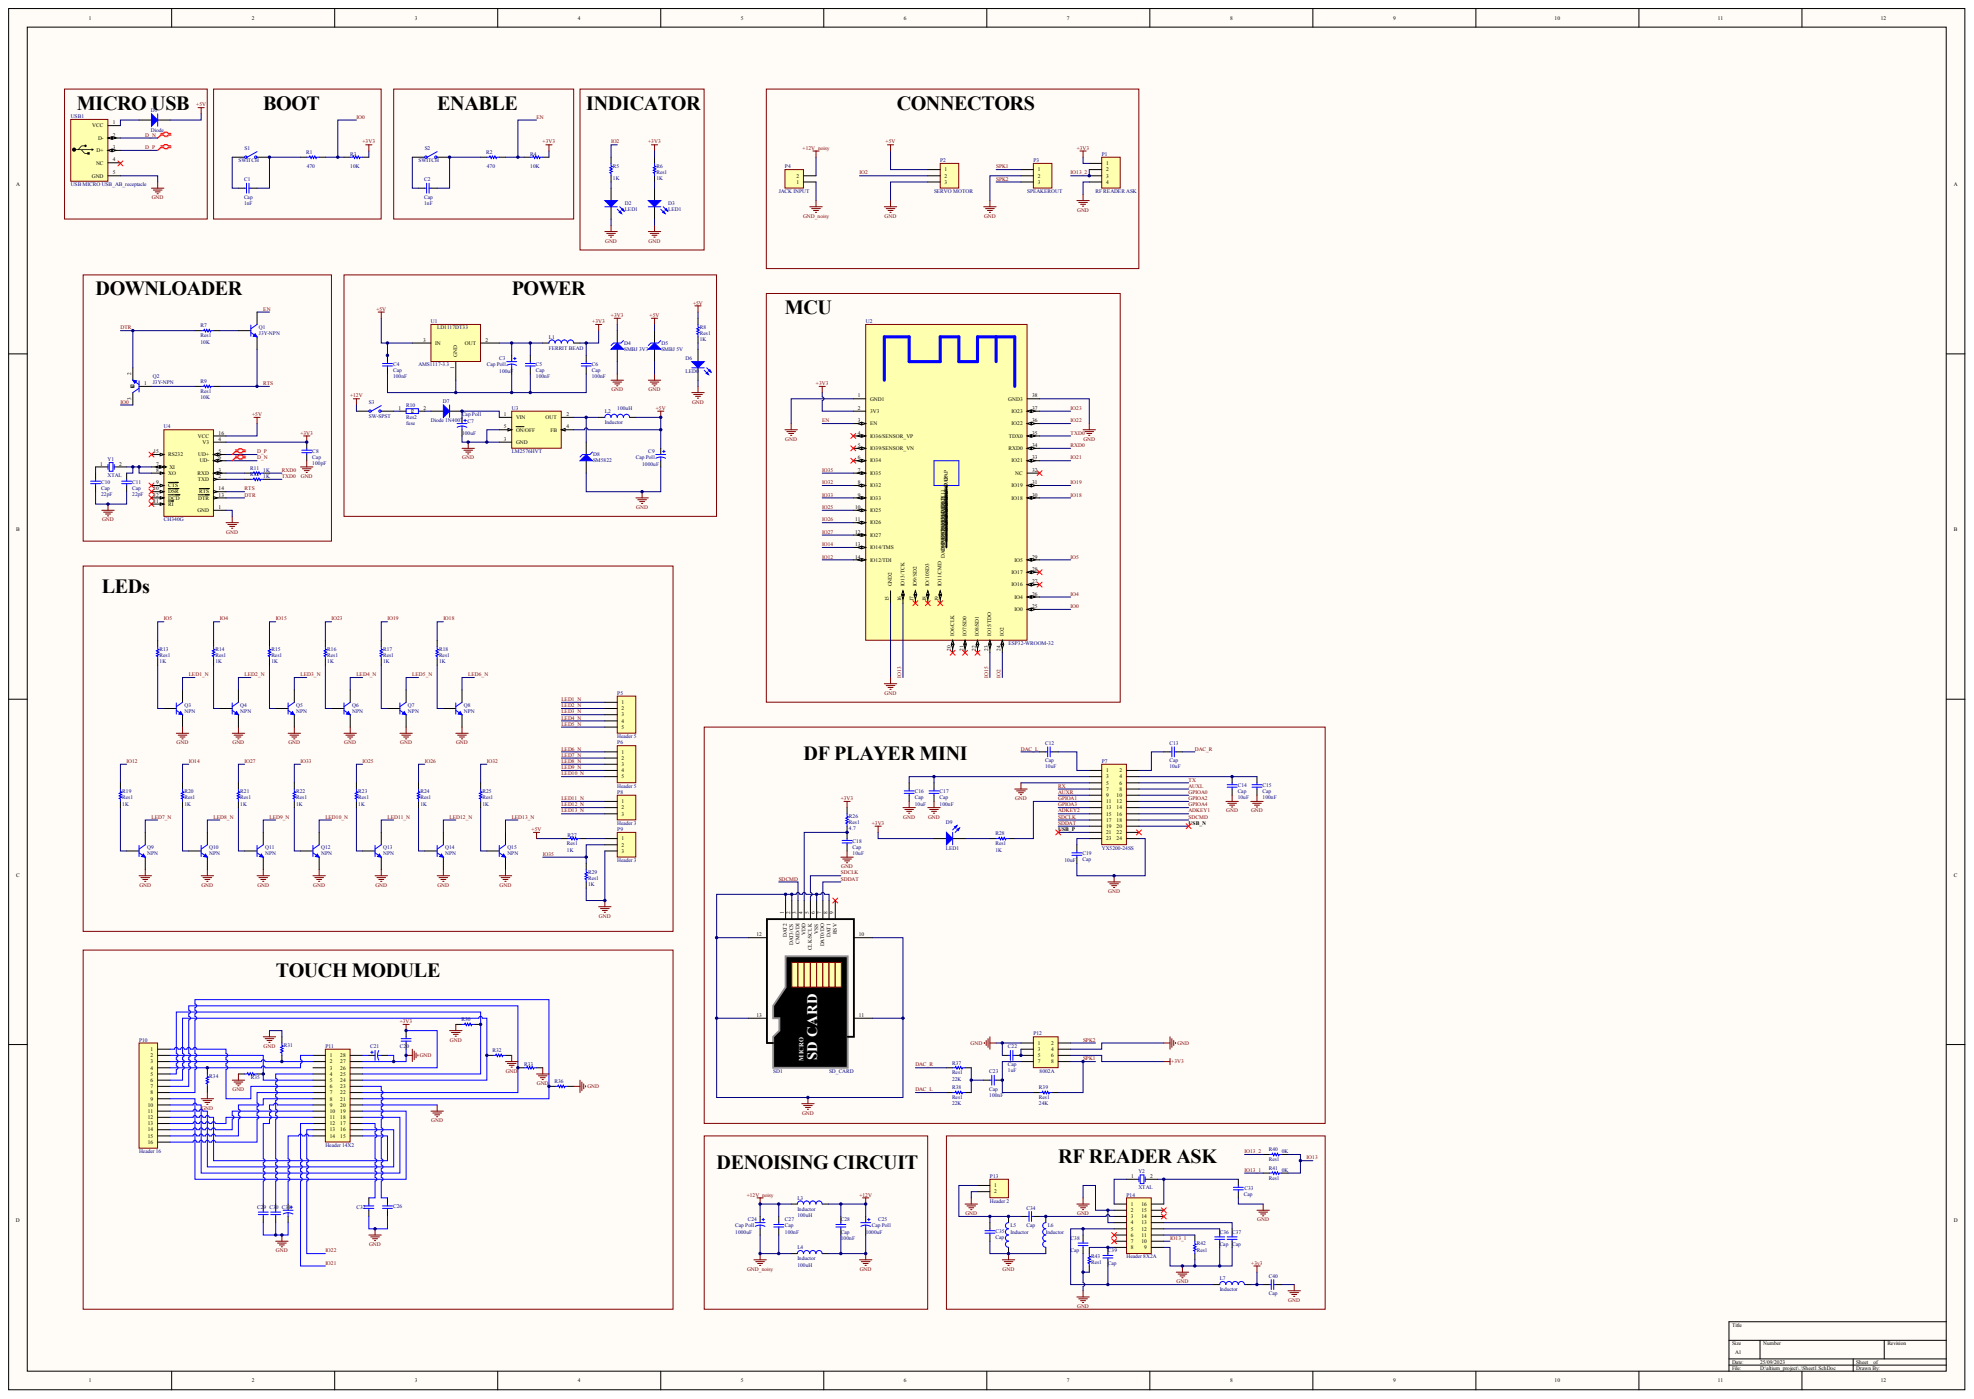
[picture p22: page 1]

DAP DAP[1] DAP DAP[2] DAP DAP[3] DAP DAP[4] DAP DAP[5] DAP DAP[6] DAP DAP[7] DAP DAP[8] DAP DAP[9]

GND

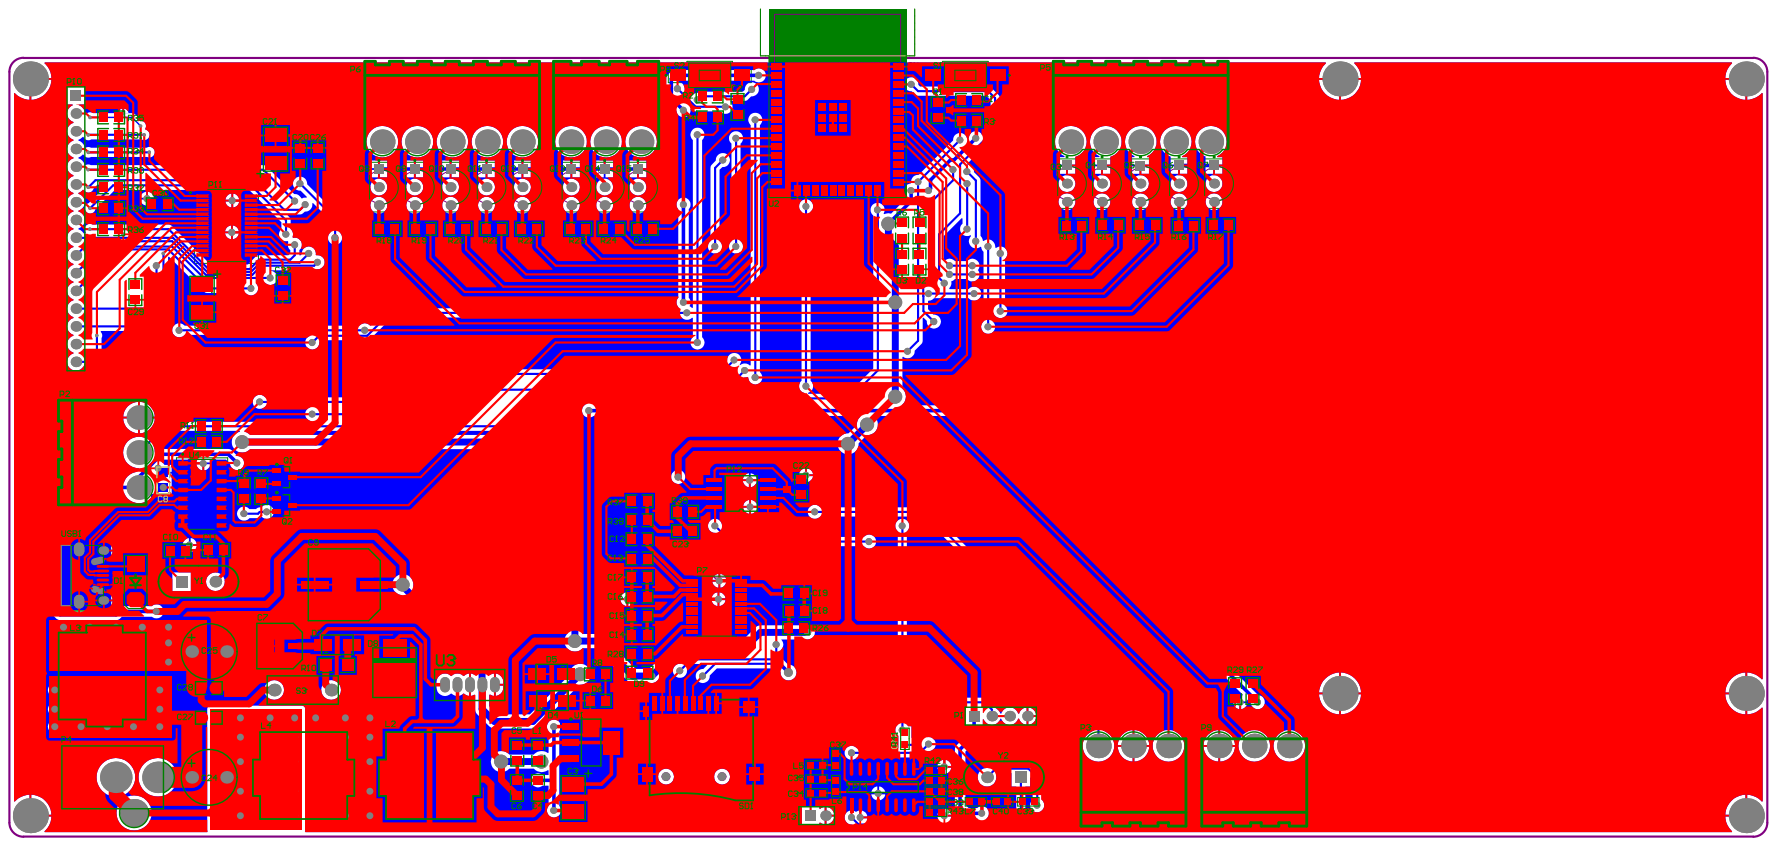
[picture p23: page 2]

Bill of Materials | <Parameter Title not found>
Source Data From: | PCB_Project1.PrjPCB
Project: | | PCB_Project1.PrjPCB
Variant: | | None

# ب.ظ 04:02:30 25/09/2023 :Date Creation

Print Date: | 45194 | 45194/66859
Footprint | Comment | LibRef | Designator | Description | Quantity
| | | C13, C14, C15, C16, C17, C18, C19, C20, C22, C23, C26, C27, C28, C29, C30, C32
smd_805 | Cap | Cap | C1, C2, C4, C5, C6, C8, C10, C11, C12,
Capacitor | 25
C_B | Cap Pol1 | Cap Pol1 | C3, C21, C31 | Polarized Capacitor (Radial) | 3

# C_CYL_SMD

2 | Cap Pol1 | Cap Pol1 | C7 | Polarized Capacitor (Radial) | 1
C_CYL_SMD | Cap Pol1 | Cap Pol1 | C9 | Polarized Capacitor (Radial) | 1
cap_pol_25v | Cap Pol1 | Cap Pol1 | C24, C25 | Polarized Capacitor (Radial) | 2
0603 | Cap | Cap | C33, C34, C35, C36, C37, C38, C39, C40 | Capacitor | 8
DO-214AC | Diode | Diode | D1 | SS110-A | 1
smd_805 | LED1 | LED1 | D2, D3, D9 | Typical RED GaAs LED | 3
TVS | SMBJ 3V3 | D Zener | D4 | Zener Diode | 1
TVS | SMBJ 5V | D Zener | D5 | Zener Diode | 1
smd_805 | LED0 | LED0 | D6 | Typical INFRARED GaAs LED | 1
TVS | Diode 1N4007 | Diode 1N4007 | D7 | 1 Amp General Purpose Rectifier | 1
DO_214_AB_ SMC | SM5822 | D Zener | D8 | Zener Diode | 1
smd_805 | FERRIT BEAD | Inductor | L1 | Inductor | 1
induc_smd | Inductor | Inductor | L2, L3, L4 | Inductor | 3
0603 | Inductor | Inductor | L5, L6, L7 | Inductor | 3
HDR1X4 | RF READER
| ASK | Header 4 | P1 | Header, 4-Pin | 1
PHOENIX_3 | SERVO
| MOTOR | Header 3 | P2 | Header, 3-Pin | 1
PHOENIX_3 | SPEAKEROUT | Header 3 | P3 | Header, 3-Pin | 1
ADAP_JACK | JACK INPUT | Header 2 | P4 | Header, 2-Pin | 1
PHOENIX_5 | Header 5 | Header 5 | P5, P6 | Header, 5-Pin | 2
21-0056C_24 | YX5200-24SS | Header 12X2 | P7 | Header, 12-Pin, Dual row | 1
PHOENIX_3 | Header 3 | Header 3 | P8, P9 | Header, 3-Pin | 2
HDR1X16 | Header 16 | Header 16 | P10 | Header, 16-Pin | 1
ssop28 | Header 14X2 | Header 14X2 | P11 | Header, 14-Pin, Dual row | 1
sop8 | 8002A | Header 4X2 | P12 | Header, 4-Pin, Dual row | 1
HDR1X2 | Header 2 | Header 2 | P13 | Header, 2-Pin | 1
SOP16 | Header 8X2A | Header 8X2A | P14 | Header, 8-Pin, Dual row | 1
sot-23 | J3Y-NPN | NPN | Q1, Q2 | NPN Bipolar Transistor | 2
to-92 | NPN | NPN | Q3, Q4, Q5, Q6, Q7, Q8, Q9, Q10, Q11,
| | | Q12, Q13, Q14, Q15 | NPN Bipolar Transistor | 13
smd_805 | Res1 | Res1 | R1, R2, R3, R4, R5, R6, R7, R8, R9, R11,
| | | R12, R13, R14, R15, R16, R17, R18,
| | | R19, R20, R21, R22, R23, R24, R25,
| | | R26, R27, R28, R29, R30, R31, R32,
| | | R33, R34, R35, R36, R37, R38, R39 | Resistor | 38
smd_1206 | Res2 | Res2 | R10 | Resistor | 1
0603 | Res1 | Res1 | R40, R41, R42, R43 | Resistor | 4
SW_SMd_2p in | SWITCH | SW-SPST | S1, S2 | Single-Pole, Single-Throw Switch | 2
KEY1 | SW-SPST | SW-SPST | S3 | Single-Pole, Single-Throw Switch | 1
SD_CARD_H OLDER | SD_CARD | MICRO_SD_CA
| | RD_HOLDER | SD1 | | 1
SOT223 | AMS1117-3.3 | LD1117DT33 | U1 | | 1
ESP32- WROOM-32 | ESP32-
| WROOM-32 | ESP32-
| | WROOM-32 | U2 | | 1
LM2576 | LM2576HVT | LM2576HVT-3.3 | U3 | SIMPLE SWITCHER® 3A Step-Down
| | | | Voltage Regulator, 5-pin TO-220 | 1
SOIC127P60 0X180-16N | CH340G | CH340G | U4 | USB Interface Integrated Circuit | 1
USB_MICRO _USB_AB_re ceptacle | USB MICRO
| USB_AB_recept
| acle | USB MICRO
| | USB_AB_recept
| | acle | USB1 | | 1
crystal | XTAL | XTAL | Y1, Y2 | Crystal Oscillator 12MHZ | 2
| | | | | 139
Approved | | Notes

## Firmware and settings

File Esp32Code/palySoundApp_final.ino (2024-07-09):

#include "functions_play_sounds.h"
short int state1 = 0;
short int state2 = 0;
unsigned int currentTime1;
boolean isOpen = true;
void setup()
{
  currentTime1=0;
  myservo.attach(2);
  myservo.write(0);
  SerialBT.begin("اسکلت سخنگو");
  Serial.begin(9600);
  Serial.println("The device started, now you can pair it with bluetooth!");
  pinMode(SCL_PIN, OUTPUT);
  pinMode(SDO_PIN, INPUT);
  mySoftwareSerial.begin(9600, SERIAL_8N1, 16, 17);  // speed, type, RX, TX
  pinMode(LEDLanguage, OUTPUT);
  pinMode(LEDJomjomeh, OUTPUT);
  pinMode(LEDKetf, OUTPUT);
  pinMode(LEDTarghove, OUTPUT);
  pinMode(LEDJenaghSine, OUTPUT);
  pinMode(LEDDandeh, OUTPUT);
  pinMode(LEDStoneMohreh, OUTPUT);
  pinMode(LEDBazo, OUTPUT);
  pinMode(LEDSaed, OUTPUT);
  pinMode(LEDDast, OUTPUT);
  pinMode(LEDLagan, OUTPUT);
  pinMode(LEDRan, OUTPUT);
  pinMode(LEDSagh, OUTPUT);
  pinMode(LEDPa, OUTPUT);
  LEDTurnOff(LEDJomjomeh);
  LEDTurnOff(LEDKetf);
  LEDTurnOff(LEDTarghove);
  LEDTurnOff(LEDJenaghSine);
  LEDTurnOff(LEDDandeh);
  LEDTurnOff(LEDStoneMohreh);
  LEDTurnOff(LEDBazo);
  LEDTurnOff(LEDSaed);
  LEDTurnOff(LEDDast);
  LEDTurnOff(LEDLagan);
  LEDTurnOff(LEDRan);
  LEDTurnOff(LEDSagh);
  LEDTurnOff(LEDPa);
  LEDTurnOff(LEDLanguage);


  mySwitch.enableReceive(13);
  if (!player.begin(mySoftwareSerial)) {  //Use softwareSerial to communicate with mp3.
    Serial.println(player.readType());
    Serial.println(F("Unable to begin:"));
    Serial.println(F("1.Please recheck the connection!"));
    Serial.println(F("2.Please insert the SD card!"));
    while (true) {
      LEDTurnOn(LEDLanguage);
      delay(1000);
      LEDTurnOff(LEDLanguage);
    }
  }
  player.setTimeOut(500); //Set serial communictaion time out 500ms
  Serial.println("OK");
  player.volume(30);
  player.EQ(DFPLAYER_EQ_NORMAL);

  player.outputDevice(DFPLAYER_DEVICE_SD);
  player.disableLoop();
}
void loop() {
  touch_sens();
  state1 = state2;
  state2 = player.readState();
  if ((state1 == 1 && state2 == 0) || (state1 == -1 && state2 == 0)) {
    LEDTurnOff(LEDJomjomeh);
    LEDTurnOff(LEDKetf);
    LEDTurnOff(LEDTarghove);
    LEDTurnOff(LEDJenaghSine);
    LEDTurnOff(LEDDandeh);
    LEDTurnOff(LEDStoneMohreh);
    LEDTurnOff(LEDBazo);
    LEDTurnOff(LEDSaed);
    LEDTurnOff(LEDDast);
    LEDTurnOff(LEDLagan);
    LEDTurnOff(LEDRan);
    LEDTurnOff(LEDSagh);
    LEDTurnOff(LEDPa);
    state1 = state2 = 0;
    myservo.write(0);
  }
  if (isOpen && millis() - currentTime1 > 700 && state1 == 1 && state2 == 1) {
    myservo.write(38);  // tell servo to go to a particular angle
    isOpen=false;
    currentTime1=millis();
  }
  if (!isOpen && millis() - currentTime1 > 700 && state1 == 1 && state2 == 1) {
    myservo.write(0);  // tell servo to go to a particular angle
    isOpen=true;
    currentTime1=millis();
  }
  if (SerialBT.available()) {
    String a = SerialBT.readString();
    int b = a.toInt();
    LEDTurnOn(LEDJomjomeh);
    LEDTurnOn(LEDKetf);
    LEDTurnOn(LEDTarghove);
    LEDTurnOn(LEDJenaghSine);
    LEDTurnOn(LEDDandeh);
    LEDTurnOn(LEDStoneMohreh);
    LEDTurnOn(LEDBazo);
    LEDTurnOn(LEDSaed);
    LEDTurnOn(LEDDast);
    LEDTurnOn(LEDLagan);
    LEDTurnOn(LEDRan);
    LEDTurnOn(LEDSagh);
    LEDTurnOn(LEDPa);
    delay(1000);
    LEDTurnOff(LEDJomjomeh);
    LEDTurnOff(LEDKetf);
    LEDTurnOff(LEDTarghove);
    LEDTurnOff(LEDJenaghSine);
    LEDTurnOff(LEDDandeh);
    LEDTurnOff(LEDStoneMohreh);
    LEDTurnOff(LEDBazo);
    LEDTurnOff(LEDSaed);
    LEDTurnOff(LEDDast);
    LEDTurnOff(LEDLagan);
    LEDTurnOff(LEDRan);
    LEDTurnOff(LEDSagh);
    LEDTurnOff(LEDPa);
    play_BT(b);
    state1 = state2 = 0;
  }
  if (mySwitch.available()) {
    LEDTurnOn(LEDJomjomeh);
    LEDTurnOn(LEDKetf);
    LEDTurnOn(LEDTarghove);
    LEDTurnOn(LEDJenaghSine);
    LEDTurnOn(LEDDandeh);
    LEDTurnOn(LEDStoneMohreh);
    LEDTurnOn(LEDBazo);
    LEDTurnOn(LEDSaed);
    LEDTurnOn(LEDDast);
    LEDTurnOn(LEDLagan);
    LEDTurnOn(LEDRan);
    LEDTurnOn(LEDSagh);
    LEDTurnOn(LEDPa);
    delay(1000);
    LEDTurnOff(LEDJomjomeh);
    LEDTurnOff(LEDKetf);
    LEDTurnOff(LEDTarghove);
    LEDTurnOff(LEDJenaghSine);
    LEDTurnOff(LEDDandeh);
    LEDTurnOff(LEDStoneMohreh);
    LEDTurnOff(LEDBazo);
    LEDTurnOff(LEDSaed);
    LEDTurnOff(LEDDast);
    LEDTurnOff(LEDLagan);
    LEDTurnOff(LEDRan);
    LEDTurnOff(LEDSagh);
    LEDTurnOff(LEDPa);
    player.stop();
    unsigned long Value = mySwitch.getReceivedValue();
    Serial.println(Value);
    if (Value == 5330691) {
      player.stop();
      if (fa) {
        Serial.println("Enable EN");
        LEDTurnOn(LEDLanguage);
        fa = false;
        delay(1000);
      }
      else {
        Serial.println("Enable FA");
        LEDTurnOff(LEDLanguage);
        fa = true;
        delay(1000);
      }
    }
    else {
      player.stop();
      switch (Value)
      {
        case 5330700:
          play_RF(1);
          break;

        case 5330736:
          play_RF(2);
          break;

        case 5330892:
          play_RF(3);
          break;

        case 5330895:
          play_RF(4);
          break;

        case 5330748:
          play_RF(5);
          break;

        case 5330751:
          play_RF(6);
          break;

        case 5330928:
          play_RF(7);
          break;

        case 5330883:
          play_RF(8);
          break;

        case 5330703:
          play_RF(9);
          break;

        case 5330940:
          play_RF(10);
          break;

        case 5330931:
          play_RF(11);
          break;

        case 5330943:
          play_RF(12);
          break;

        case 5330880:
          play_RF(13);
          break;

        case 5330739:
          //player.volumeDown();
          break;

        case 5330688:
          //player.volumeUp();
          break;

        default :
          break;

      }
    }
    mySwitch.resetAvailable();
    state1 = state2 = 0;
  }

}

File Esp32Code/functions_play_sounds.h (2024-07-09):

#include <ESP32Servo.h>
#include <analogWrite.h>

#include <Arduino.h>
#include "DFRobotDFPlayerMini.h"
#include <RCSwitch.h>
#include "BluetoothSerial.h"
#if !defined(CONFIG_BT_ENABLED) || !defined(CONFIG_BLUEDROID_ENABLED)
#error Bluetooth is not enabled! Please run `make menuconfig` to and enable it
#endif

#if !defined(CONFIG_BT_SPP_ENABLED)
#error Serial Bluetooth not available or not enabled. It is only available for the ESP32 chip.
#endif
#define LEDJomjomeh 5
#define LEDKetf 4
#define LEDTarghove 15
#define LEDJenaghSine 23
#define LEDDandeh 19
#define LEDStoneMohreh 18
#define LEDBazo 12
#define LEDSaed 14
#define LEDDast 27
#define LEDLagan 33
#define LEDRan 25
#define LEDSagh 26
#define LEDPa 32
#define LEDLanguage 35
#define SCL_PIN 22
#define SDO_PIN 21

BluetoothSerial SerialBT;
RCSwitch mySwitch = RCSwitch();
bool fa = true;
byte key;
byte keyIsTrue;
bool doIt = false;
unsigned int currentTime;

HardwareSerial mySoftwareSerial(1);
DFRobotDFPlayerMini player;
Servo myservo;
void LEDTurnOff(int in) {
  digitalWrite(in, LOW);
}
void LEDTurnOn(int in) {
  digitalWrite(in, HIGH);
}
void play_BT(int input) {
  player.stop();
  switch (input) {

    case 1:
      player.playMp3Folder(1);  //0001-jomjome-fa.mp3
      LEDTurnOn(LEDJomjomeh);
      break;

    case 2:
      player.playMp3Folder(2);  //0002-jomjome-en.mp3
      LEDTurnOn(LEDJomjomeh);
      break;

    case 3:
      player.playMp3Folder(3);  //0003-targhove-fa.mp3
      LEDTurnOn(LEDTarghove);
      break;

    case 4:
      player.playMp3Folder(4);  //0004-targhove-en.mp3
      LEDTurnOn(LEDTarghove);
      break;

    case 5:
      player.playMp3Folder(5);  //0005-ketf-fa.mp3
      LEDTurnOn(LEDKetf);
      break;

    case 6:
      player.playMp3Folder(6);  //0006-ketf-en.mp3
      LEDTurnOn(LEDKetf);
      break;

    case 7:
      player.playMp3Folder(7);  //0007-jenagh sine-fa.mp3
      LEDTurnOn(LEDJenaghSine);
      break;

    case 8:
      player.playMp3Folder(8);  //0008-jenagh sine-en.mp3
      LEDTurnOn(LEDJenaghSine);
      break;

    case 9:
      player.playMp3Folder(9);  //0009-dandeha-fa.mp3
      LEDTurnOn(LEDDandeh);
      break;

    case 10:
      player.playMp3Folder(10);  //0010-dande ha-en.mp3
      LEDTurnOn(LEDDandeh);
      break;

    case 11:
      player.playMp3Folder(11);  //0011-sotun mohre-fa.mp3
      LEDTurnOn(LEDStoneMohreh);
      break;

    case 12:
      player.playMp3Folder(12);  //0012-sotun mohre-en.mp3
      LEDTurnOn(LEDStoneMohreh);
      break;

    case 13:
      player.playMp3Folder(13);  //0013-bazoo-fa.mp3
      LEDTurnOn(LEDBazo);
      break;

    case 14:
      player.playMp3Folder(14);  //0014-bazoo-en.mp3
      LEDTurnOn(LEDBazo);
      break;

    case 15:
      player.playMp3Folder(15);  //0015-saed-fa.mp3
      LEDTurnOn(LEDSaed);
      break;

    case 16:
      player.playMp3Folder(16);  //0016-saed-en.mp3
      LEDTurnOn(LEDSaed);
      break;

    case 17:
      player.playMp3Folder(17);  //0017-moch & angoshtan dast-fa.mp3
      LEDTurnOn(LEDDast);
      break;

    case 18:
      player.playMp3Folder(18);  //0018-moch & angoshtan dast-en.mp3
      LEDTurnOn(LEDDast);
      break;

    case 19:
      player.playMp3Folder(19);  //0019-lagan-fa.mp3
      LEDTurnOn(LEDLagan);
      break;

    case 20:
      player.playMp3Folder(20);  //0020-lagan-en.mp3
      LEDTurnOn(LEDLagan);
      break;

    case 21:
      player.playMp3Folder(21);  //0021-ran-fa.mp3
      LEDTurnOn(LEDRan);
      break;

    case 22:
      player.playMp3Folder(22);  //0022-ran-en.mp3
      LEDTurnOn(LEDRan);
      break;

    case 23:
      player.playMp3Folder(23);  //0023-sagh-fa.mp3
      LEDTurnOn(LEDSagh);
      break;

    case 24:
      player.playMp3Folder(24);  //0024-sagh-en.mp3
      LEDTurnOn(LEDSagh);
      break;

    case 25:
      player.playMp3Folder(25);  //0025-moch & angoshtan pa-fa.mp3
      LEDTurnOn(LEDPa);
      break;

    case 26:
      player.playMp3Folder(26);  //0026-moch & angoshtan pa-en.mp3
      LEDTurnOn(LEDPa);
      break;

    default:
      break;
  }
  delay(1000);
}

void play_RF(int v) {
  player.stop();
  switch (v) {

    case 1:
      if (fa) {
        player.playMp3Folder(1);  //0001-jomjome-fa.mp3
      } else {
        player.playMp3Folder(2);  //0002-jomjome-en.mp3
      }
      LEDTurnOn(LEDJomjomeh);
      break;

    case 2:
      if (fa) {
        player.playMp3Folder(5);  //0005-ketf-fa.mp3
      } else {
        player.playMp3Folder(6);  //0006-ketf-en.mp3
      }
      LEDTurnOn(LEDKetf);
      break;

    case 3:
      if (fa) {
        player.playMp3Folder(3);  //0003-targhove-fa.mp3
      } else {
        player.playMp3Folder(4);  //0004-targhove-en.mp3
      }
      LEDTurnOn(LEDTarghove);
      break;

    case 4:
      if (fa) {
        player.playMp3Folder(7);  //0007-jenagh sine-fa.mp3
      } else {
        player.playMp3Folder(8);  //0008-jenagh sine-en.mp3
      }
      LEDTurnOn(LEDJenaghSine);
      break;

    case 5:
      if (fa) {
        player.playMp3Folder(9);  //0009-dandeha-fa.mp3
      } else {
        player.playMp3Folder(10);  //0010-dande ha-en.mp3
      }
      LEDTurnOn(LEDDandeh);
      break;

    case 6:
      if (fa) {
        player.playMp3Folder(11);  //0011-sotun mohre-fa.mp3
      } else {
        player.playMp3Folder(12);  //0012-sotun mohre-en.mp3
      }
      LEDTurnOn(LEDStoneMohreh);
      break;

    case 7:
      if (fa) {
        player.playMp3Folder(13);  //0013-bazoo-fa.mp3
      } else {
        player.playMp3Folder(14);  //0014-bazoo-en.mp3
      }
      LEDTurnOn(LEDBazo);
      break;

    case 8:
      if (fa) {
        player.playMp3Folder(15);  //0015-saed-fa.mp3
      } else {
        player.playMp3Folder(16);  //0016-saed-en.mp3
      }
      LEDTurnOn(LEDSaed);
      break;

    case 9:
      if (fa) {
        player.playMp3Folder(17);  //0017-moch & angoshtan dast-fa.mp3
      } else {
        player.playMp3Folder(18);  //0018-moch & angoshtan dast-en.mp3
      }
      LEDTurnOn(LEDDast);
      break;

    case 10:
      if (fa) {
        player.playMp3Folder(19);  //0019-lagan-fa.mp3
      } else {
        player.playMp3Folder(20);  //0020-lagan-en.mp3
      }
      LEDTurnOn(LEDLagan);
      break;

    case 11:
      if (fa) {
        player.playMp3Folder(21);  //0021-ran-fa.mp3
      } else {
        player.playMp3Folder(22);  //0022-ran-en.mp3
      }
      LEDTurnOn(LEDRan);
      break;

    case 12:
      if (fa) {
        player.playMp3Folder(23);  //0023-sagh-fa.mp3
      } else {
        player.playMp3Folder(24);  //0024-sagh-en.mp3
      }
      LEDTurnOn(LEDSagh);
      break;

    case 13:
      if (fa) {
        player.playMp3Folder(25);  //0025-moch & angoshtan pa-fa.mp3
      } else {
        player.playMp3Folder(26);  //0026-moch & angoshtan pa-en.mp3
      }
      LEDTurnOn(LEDPa);
      break;
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
